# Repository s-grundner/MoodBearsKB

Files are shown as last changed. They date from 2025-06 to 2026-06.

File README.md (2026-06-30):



# Custom Keyboard

Personalized Totem Keyboard: PCB and Case Completely reworked.

Inspirations:

- [TOTEM Keyboard](https://github.com/GEIGEIGEIST/TOTEM)

## Revision 1

Revision 1 is focused on using parts i have at home. This impedes the case design a little bit though, as the THT diodes intersect with the Original switch plate

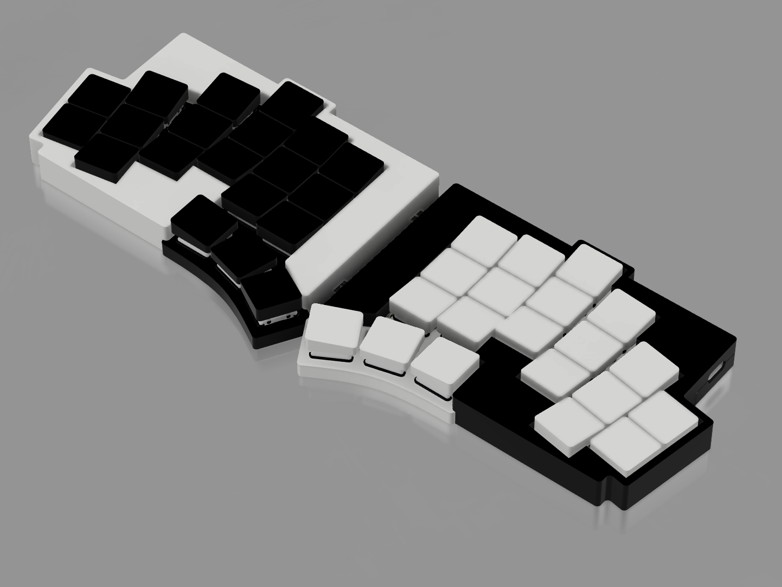
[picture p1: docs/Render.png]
KB
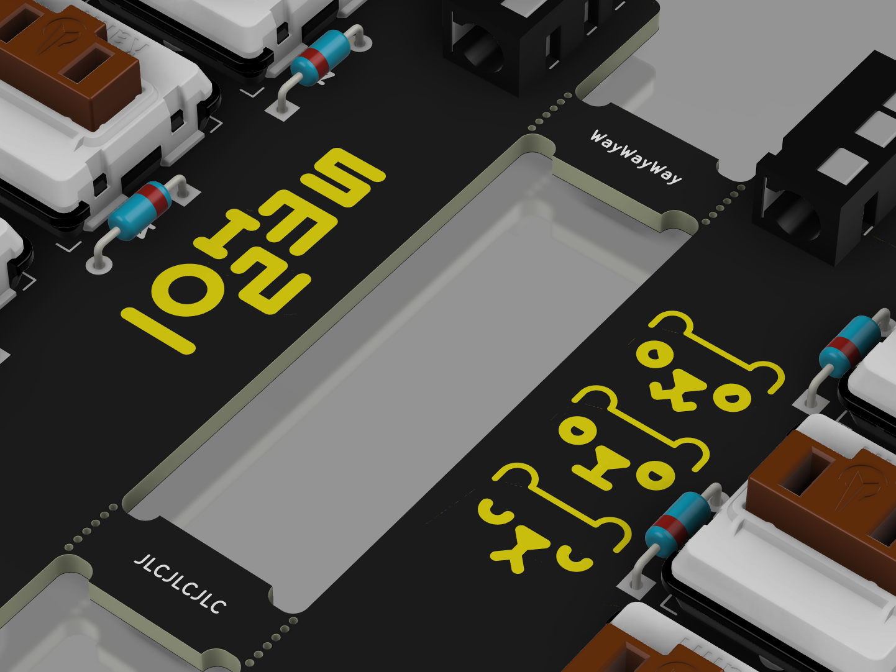
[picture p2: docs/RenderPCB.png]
PCB
|  |  |
| :---: | :---: |
| Keyboard Preview | PCB |

```text
// Template 
//             ┏━━━━━━━━━━━┳━━━━━━━━━━━┳━━━━━━━━━━━┳━━━━━━━━━━━┳━━━━━━━━━━━┓   ┏━━━━━━━━━━━┳━━━━━━━━━━━┳━━━━━━━━━━━┳━━━━━━━━━━━┳━━━━━━━━━━━┓
//             ┃           ┃           ┃           ┃           ┃           ┃   ┃           ┃           ┃           ┃           ┃           ┃
// ┏━━━━━━━━━━━╋━━━━━━━━━━━╋━━━━━━━━━━━╋━━━━━━━━━━━╋━━━━━━━━━━━╋━━━━━━━━━━━┫   ┣━━━━━━━━━━━╋━━━━━━━━━━━╋━━━━━━━━━━━╋━━━━━━━━━━━╋━━━━━━━━━━━╋━━━━━━━━━━━┓
// ┃    ESC    ┃           ┃    ALT    ┃   CTRL    ┃   SHIFT   ┃           ┃   ┃           ┃   SHIFT   ┃   CTRL    ┃    ALT    ┃           ┃   BSPC    ┃
// ┣━━━━━━━━━━━╋━━━━━━━━━━━╋━━━━━━━━━━━╋━━━━━━━━━━━╋━━━━━━━━━━━╋━━━━━━━━━━━┫   ┣━━━━━━━━━━━╋━━━━━━━━━━━╋━━━━━━━━━━━╋━━━━━━━━━━━╋━━━━━━━━━━━╋━━━━━━━━━━━┫
// ┃    TAB    ┃           ┃           ┃           ┃           ┃           ┃   ┃           ┃           ┃           ┃           ┃           ┃   ENTER   ┃
// ┗━━━━━━━━━━━┻━━━━━━━━━━━┻━━━━━━━━━━━╋━━━━━━━━━━━╋━━━━━━━━━━━╋━━━━━━━━━━━┫   ┣━━━━━━━━━━━╋━━━━━━━━━━━╋━━━━━━━━━━━╋━━━━━━━━━━━┻━━━━━━━━━━━┻━━━━━━━━━━━┛
//                                     ┃   SUPER   ┃    SYM    ┃    SPC    ┃   ┃    SPC    ┃    NUM    ┃    DEL    ┃
//                                     ┗━━━━━━━━━━━┻━━━━━━━━━━━┻━━━━━━━━━━━┛   ┗━━━━━━━━━━━┻━━━━━━━━━━━┻━━━━━━━━━━━┛
```

## Firmware Update

1. Flash settings_reset to dongle, left, and right.
2. Reboot/power-cycle all three devices.
3. Flash normal firmware to dongle first.
4. Reboot dongle.
5. Flash normal firmware to left and right.
6. Reboot each half again.
7. Wait for the halves to pair to the dongle.

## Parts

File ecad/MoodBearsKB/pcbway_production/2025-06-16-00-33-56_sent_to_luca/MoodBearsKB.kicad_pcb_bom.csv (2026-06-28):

Designator | Quantity | Value | Footprint | Package | MPN | DNP | Mount_Type
BAT+1, BAT+2 | 2 | + | BatteryPad |  |  |  | tht
BATGND1, BATGND2 | 2 | - | BatteryPad |  |  |  | tht
DL1, DL10, DL11, DL12, DL13, DL14, DL15, DL16, DL17, DL18, DL19, DL2, DL20, DL3, DL4, DL5, DL6, DL7, DL8, DL9, DR1, DR10, DR11, DR12, DR13, DR14, DR15, DR16, DR17, DR18, DR19, DR2, DR20, DR3, DR4, DR5, DR6, DR7, DR8, DR9 | 40 | D_Small | Diode_SOD27 |  |  |  | tht
J1, J2 | 2 | MJ-4PP-9 | MJ-4PP-9_1side |  |  |  | tht
PSW1, PSW2 | 2 | SW_SPDT | MSK12C02 |  |  |  | smt
RSW1, RSW2 | 2 | SW_Push | SKHLLCA010 |  |  |  | tht
SWL1, SWL10, SWL11, SWL12, SWL13, SWL14, SWL15, SWL16, SWL17, SWL18, SWL19, SWL2, SWL20, SWL3, SWL4, SWL5, SWL6, SWL7, SWL8, SWL9, SWR1, SWR10, SWR11, SWR12, SWR13, SWR14, SWR15, SWR16, SWR17, SWR18, SWR19, SWR2, SWR20, SWR3, SWR4, SWR5, SWR6, SWR7, SWR8, SWR9 | 40 | SW_Push_45deg | Kailh_socket_PG1350_optional |  |  |  | tht
U1, U2 | 2 | xiao-ble | xiao-ble-smd-cutout |  |  |  | tht

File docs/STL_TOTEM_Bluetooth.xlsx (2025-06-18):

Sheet: Notizblatt
Stückliste Notizblatt
Lfd. Nr. | Stück- zahl | Ein- heit | Benennung | Referenzkennzeichen | Lieferant | Bestellnummer | MCd | Preis/EH | VE | Bemerkung
1 | 40 | STK | Choc V1 Switches | SWL1-20, SWR1-20 | keeb.supply |  |  | 0.950 | 10 | Ambients Silent Linear Twilight (https://keeb.supply/products/twilight-low-profile-switches?variant=98b7ff54-19e0-47d5-9570-212822195d1c)
2 | 40 | STK | Kailh-Choc 1350 Hot Swap Sockets | SWL1-20, SWR1-20 | keeb.supply |  |  | 0.220 | 10 | Choc Kailh hotswap sockets (https://keeb.supply/products/kailh-hotswap-sockets?variant=2ac70e4a-befb-43b0-9321-8c5636b8d5d3)
3 | 40 | STK | 1N4148 | DL1-20, DR1-20 | s-grundner (https://github.com/s-grundner) | 1N 4148 |  | 0.000 | 1 | THT version
4 | 2 | STK | Reset Button | RSW1,2 | keeb.supply | SKHLLCA010 |  | 0.6 | 1 | Alps
5 | 1 | STK | PCB |  | l-langegger |  |  | 0 | 5 | PCB-Way via Sammelbestellung
6 | 2 | STK | LiPo Akku 3.7V |  | reichelt.de | AKKU 30851 |  | 5.300 | 1 | 140mAh, L=24.4mm, B=13.1mm, H=6.1mm
7 | 3 | STK | Seeed Studio XIAO nRF52840 | U1,2 | reichelt.de | XIAO NRF52840 |  | 12.800 | 1
8 | 2 | STK | SPST Power Switch | PSW1,2 | keeb.supply (https://keebd.com/en-de) | MSK-12C02 |  | 0.800 | 1 | Switch Mini 7 Pin 2 Slide Positions (https://keeb.supply/products/smd-slide-switch?variant=c8e601de-b898-4b81-b8a4-a918e330e673)
9 | 4 | STK | Gummi Füße |  | amazon.de |  |  | 0.040 | 100 | Round Silicone Rubber Feet (https://www.amazon.de/dp/B076ND94QV?psc=1&ref_=cm_sw_r_cp_ud_ct_W7SYHVF00B5TN0Z39RR0)
10 | 4 | STK | Brass Standoffs
11 | 1 | STK | Shipping Reichelt |  |  |  |  | 5.95 | 1
12 | 1 | STK | Shipping JLC |  |  |  |  |  | 1
Nach dieser Linie dürfen keine Daten mehr eingegeben werden

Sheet: Eingabe
Jahrgang: |  |  |  |  |  | Toleranz: |  |  |  | Dokumentart: | Stückliste | Sachnummer, Dateiname:
Katalognummer: |  |  |  |  |  | Werkstoff: |  | FR4 |  | Datum: | 2025-06-16 | Stückliste:
Vorname Nachname: |  |  |  | Simon Grundner |  | Geprüft : |  |  |  | Version: | 1.0 | Materialkalkulation:
Kurzzeichen: |  |  |  | GruS |  | Betreuer: |  |  |  | Revision: | 1 | Einheiten zur Bestellung: |  | 1
Benennung (Projekt) / Version: |  |  |  | TOTEM - Bluetooth |  | Freigabe. |  |  |  | Dokumentenstatus: | Fertigung | Ausbildungsrichtung:
Benennung (Projekt) Zeile 2: |  |  |  | 40 Key Split Ergomech KB |  | Sprache: |  | DE |  | Maßstab: | ohne | Technische Informatik
Lfd. Nr. | Stück- zahl | Ein- heit | Benennung | Referenzkennzeichen | Lieferant | Bestellnummer | MCd | Preis/EH | VE | Bemerkung | Preisvorschau 135.42 €/STK | 1 EH inkl. 10% GK = 112.85 € zuzgl. 20% MwSt. = 135.42 € Bestellnummer Bestellmenge Bestelltextkontrolle - Ben. Ref.KZ - keine Feldlängenkontrolle
1 | 40 | STK | Choc V1 Switches | SWL1-20, SWR1-20 | keeb.supply |  |  | 0.95 | 10 | Ambients Silent Linear Twilight (https://keeb.supply/products/twilight-low-profile-switches?variant=98b7ff54-19e0-47d5-9570-212822195d1c) | 38.0000 | 0 | 40 STK | Choc V1 Switches SWL1-20, SWR1-20
2 | 40 | STK | Kailh-Choc 1350 Hot Swap Sockets | SWL1-20, SWR1-20 | keeb.supply |  |  | 0.22 | 10 | Choc Kailh hotswap sockets (https://keeb.supply/products/kailh-hotswap-sockets?variant=2ac70e4a-befb-43b0-9321-8c5636b8d5d3) | 8.8000 | 0 | 40 STK | Kailh-Choc 1350 Hot Swap Sockets SWL1-20, SWR1-20
3 | 40 | STK | 1N4148 | DL1-20, DR1-20 | s-grundner (https://github.com/s-grundner) | 1N 4148 |  | 0 | 1 | THT version
4 | 2 | STK | Reset Button | RSW1,2 | keeb.supply | SKHLLCA010 |  | 0.6 | 1 | Alps | 1.2000 | SKHLLCA010 | 2 STK | Reset Button RSW1,2
5 | 1 | STK | PCB |  | l-langegger |  |  | 0 | 5 | PCB-Way via Sammelbestellung
6 | 2 | STK | LiPo Akku 3.7V |  | reichelt.de | AKKU 30851 |  | 5.3 | 1 | 140mAh, L=24.4mm, B=13.1mm, H=6.1mm | 10.6000 | AKKU 30851 | 2 STK | LiPo Akku 3.7V
7 | 3 | STK | Seeed Studio XIAO nRF52840 | U1,2 | reichelt.de | XIAO NRF52840 |  | 12.8 | 1 |  | 38.4000 | XIAO NRF52840 | 3 STK | Seeed Studio XIAO nRF52840 U1,2
8 | 2 | STK | SPST Power Switch | PSW1,2 | keeb.supply (https://keebd.com/en-de) | MSK-12C02 |  | 0.8 | 1 | Switch Mini 7 Pin 2 Slide Positions (https://keeb.supply/products/smd-slide-switch?variant=c8e601de-b898-4b81-b8a4-a918e330e673) | 1.6000 | MSK-12C02 | 2 STK | SPST Power Switch PSW1,2
9 | 4 | STK | Gummi Füße |  | amazon.de |  |  | 0.0399 | 100 | Round Silicone Rubber Feet (https://www.amazon.de/dp/B076ND94QV?psc=1&ref_=cm_sw_r_cp_ud_ct_W7SYHVF00B5TN0Z39RR0) | 3.9900 | 0 | 100 STK | Gummi Füße
1
11
12
13
14
15
16
17
18
19
20
21
22
23
24
25
26
27
28
29
30
31

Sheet: Stückliste (1)
1 | 2 | 3 | 4 |  | 5 |  |  |  |  | 6 |  | 7
Lfd. Nr. | Stück- zahl | Ein- heit | Benennung |  | Lieferant / Bestellnummer |  |  |  |  | MCd |  | Bemerkung
1 | 40 | STK | Choc V1 Switches SWL1-20, SWR1-20 |  | keeb.supply |  |  |  |  |  |  | Ambients Silent Linear Twilight
2 | 40 | STK | Kailh-Choc 1350 Hot Swap Sockets SWL1-20, SWR1-20 |  | keeb.supply |  |  |  |  |  |  | Choc Kailh hotswap sockets
3 | 40 | STK | 1N4148 DL1-20, DR1-20 |  | s-grundner 1N 4148 |  |  |  |  |  |  | THT version
4 | 2 | STK | Reset Button RSW1,2 |  | keeb.supply SKHLLCA010 |  |  |  |  |  |  | Alps
5 | 1 | STK | PCB |  | l-langegger |  |  |  |  |  |  | PCB-Way via Sammelbestellung
6 | 2 | STK | LiPo Akku 3.7V |  | reichelt.de AKKU 30851 |  |  |  |  |  |  | 140mAh, L=24.4mm, B=13.1mm, H=6.1mm
7 | 3 | STK | Seeed Studio XIAO nRF52840 U1,2 |  | reichelt.de XIAO NRF52840
8 | 2 | STK | SPST Power Switch PSW1,2 |  | keeb.supply MSK-12C02 |  |  |  |  |  |  | Switch Mini 7 Pin 2 Slide Positions
9 | 4 | STK | Gummi Füße |  | amazon.de |  |  |  |  |  |  | Round Silicone Rubber Feet
1
11
12
13
14
15
16
17
18
19
20
21
22
23
24
25
Sachnummer, Dateiname: |  |  |  | Name: |  |  |  | Toleranz: |  |  |  | Werkstoff:
 |  |  |  | Simon Grundner |  |  |  |  |  |  |  | FR4
 |  |  |  | ID-Nr.: | Gez.: | Geprüft: | Betreuer: | Dokumentart:
 |  |  |  |  | GruS |  |  | Stückliste
 |  |  |  | Benennung: |  |  |  | Version: |  |  | Revision: |  | Dokumentenstatus:
 |  |  |  | TOTEM - Bluetooth |  |  |  | 1.0 |  |  | 1 |  | Fertigung
HTBLuVA Salzburg
 |  |  |  |  |  |  |  | Maßstab: | Spr.: |  | Datum:
Technische Informatik |  |  |  | 40 Key Split Ergomech KB |  |  |  | ohne | DE |  | 2025-06-16

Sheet: Stückliste (2)
1 | 2 | 3 | 4 |  | 5 |  |  |  |  | 6 |  | 7
Lfd. Nr. | Stück- zahl | Ein- heit | Benennung |  | Lieferant / Bestellnummer |  |  |  |  | MCd |  | Bemerkung
26
27
28
29
30
31
Sachnummer, Dateiname: |  |  |  | Name: |  |  |  | Toleranz: |  |  |  | Werkstoff:
 |  |  |  | Simon Grundner |  |  |  |  |  |  |  | FR4
 |  |  |  | ID-Nr.: | Gez.: | Geprüft: | Betreuer: | Dokumentart:
 |  |  |  |  | GruS |  |  | Stückliste
 |  |  |  | Benennung: |  |  |  | Version: |  |  | Revision: |  | Dokumentenstatus:
 |  |  |  | TOTEM - Bluetooth |  |  |  | 1.0 |  |  | 1 |  | Fertigung
HTBLuVA Salzburg
 |  |  |  |  |  |  |  | Maßstab: | Spr.: |  | Datum:
Technische Informatik |  |  |  | 40 Key Split Ergomech KB |  |  |  | ohne | DE |  | 2025-06-16

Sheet: Stückliste (3)
1 | 2 | 3 | 4 |  | 5 |  |  |  |  | 6 |  | 7
Lfd. Nr. | Stück- zahl | Ein- heit | Benennung |  | Lieferant / Bestellnummer |  |  |  |  | MCd |  | Bemerkung
Sachnummer, Dateiname: |  |  |  | Name: |  |  |  | Toleranz: |  |  |  | Werkstoff:
 |  |  |  | Simon Grundner |  |  |  |  |  |  |  | FR4
 |  |  |  | ID-Nr.: | Gez.: | Geprüft: | Betreuer: | Dokumentart:
 |  |  |  |  | GruS |  |  | Stückliste
 |  |  |  | Benennung: |  |  |  | Version: |  |  | Revision: |  | Dokumentenstatus:
 |  |  |  | TOTEM - Bluetooth |  |  |  | 1.0 |  |  | 1 |  | Fertigung
HTBLuVA Salzburg
 |  |  |  |  |  |  |  | Maßstab: | Spr.: |  | Datum:
Technische Informatik |  |  |  | 40 Key Split Ergomech KB |  |  |  | ohne | DE |  | 2025-06-16

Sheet: Stückliste (4)
1 | 2 | 3 | 4 |  | 5 |  |  |  |  | 6 |  | 7
Lfd. Nr. | Stück- zahl | Ein- heit | Benennung |  | Lieferant / Bestellnummer |  |  |  |  | MCd |  | Bemerkung
Sachnummer, Dateiname: |  |  |  | Name: |  |  |  | Toleranz: |  |  |  | Werkstoff:
 |  |  |  | Simon Grundner |  |  |  |  |  |  |  | FR4
 |  |  |  | ID-Nr.: | Gez.: | Geprüft: | Betreuer: | Dokumentart:
 |  |  |  |  | GruS |  |  | Stückliste
 |  |  |  | Benennung: |  |  |  | Version: |  |  | Revision: |  | Dokumentenstatus:
 |  |  |  | TOTEM - Bluetooth |  |  |  | 1.0 |  |  | 1 |  | Fertigung
HTBLuVA Salzburg
 |  |  |  |  |  |  |  | Maßstab: | Spr.: |  | Datum:
Technische Informatik |  |  |  | 40 Key Split Ergomech KB |  |  |  | ohne | DE |  | 2025-06-16

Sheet: Stückliste (5)
1 | 2 | 3 | 4 |  | 5 |  |  |  |  | 6 |  | 7
Lfd. Nr. | Stück- zahl | Ein- heit | Benennung |  | Lieferant / Bestellnummer |  |  |  |  | MCd |  | Bemerkung
Sachnummer, Dateiname: |  |  |  | Name: |  |  |  | Toleranz: |  |  |  | Werkstoff:
 |  |  |  | Simon Grundner |  |  |  |  |  |  |  | FR4
 |  |  |  | ID-Nr.: | Gez.: | Geprüft: | Betreuer: | Dokumentart:
 |  |  |  |  | GruS |  |  | Stückliste
 |  |  |  | Benennung: |  |  |  | Version: |  |  | Revision: |  | Dokumentenstatus:
 |  |  |  | TOTEM - Bluetooth |  |  |  | 1.0 |  |  | 1 |  | Fertigung
HTBLuVA Salzburg
 |  |  |  |  |  |  |  | Maßstab: | Spr.: |  | Datum:
Technische Informatik |  |  |  | 40 Key Split Ergomech KB |  |  |  | ohne | DE |  | 2025-06-16

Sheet: Materialkalkulation (1)
1 | 2 | 3 | 4 |  |  | 5 |  |  |  |  |  |  | 6
Lfd. Nr. | Stück- zahl | Ein- heit | Benennung |  |  | Lieferant / Bestellnummer |  |  |  |  |  |  | Preis
 |  |  |  |  |  |  |  |  |  |  |  |  | Einzel
1 | 40 | STK | Choc V1 Switches |  |  | keeb.supply / |  |  |  |  |  |  | 0.950
2 | 40 | STK | Kailh-Choc 1350 Hot Swap Sockets |  |  | keeb.supply / |  |  |  |  |  |  | 0.220
3 | 40 | STK | 1N4148 |  |  | s-grundner / 1N 4148 |  |  |  |  |  |  | 0.000
4 | 2 | STK | Reset Button |  |  | keeb.supply / SKHLLCA010 |  |  |  |  |  |  | 0.600
5 | 1 | STK | PCB |  |  | l-langegger / |  |  |  |  |  |  | 0.000
6 | 2 | STK | LiPo Akku 3.7V |  |  | reichelt.de / AKKU 30851 |  |  |  |  |  |  | 5.300
7 | 3 | STK | Seeed Studio XIAO nRF52840 |  |  | reichelt.de / XIAO NRF52840 |  |  |  |  |  |  | 12.800
8 | 2 | STK | SPST Power Switch |  |  | keeb.supply / MSK-12C02 |  |  |  |  |  |  | 0.800
9 | 4 | STK | Gummi Füße |  |  | amazon.de / |  |  |  |  |  |  | 0.040
1
11
12
13
14
15
16
17
18
19
20
21
22
23
24
25
26
27
28
29
30
31
 |  |  |  |  |  | Übertrag:
 |  |  |  |  |  | Materialpreis |  |  |  |  |  |  | €98.760
 |  |  |  |  |  | Materialgemeinkosten (10%) |  |  |  |  |  |  | €9.876
 |  |  |  |  |  | Materialverkaufspreis |  |  |  |  |  |  | €108.636
Sachnummer, Dateiname: |  |  |  | Name: |  |  |  |  | Toleranz: |  |  | Werkstoff:
 |  |  |  | Simon Grundner |  |  |  |  |  |  |  | FR4
 |  |  |  | ID-Nr.: | Gez.: |  | Geprüft: | Betreuer: | Dokumentart:
 |  |  |  |  | GruS |  |  |  | Materialkalkulation
 |  |  |  | Benennung: |  |  |  |  | Version: |  | Revision: |  | Dokumentenstatus:
 |  |  |  | TOTEM - Bluetooth |  |  |  |  | 1.0 |  | 1 |  | Fertigung
HTBLuVA Salzburg
 |  |  |  |  |  |  |  |  | Maßstab: | Spr.: | Datum:
Technische Informatik |  |  |  | 40 Key Split Ergomech KB |  |  |  |  | ohne | DE | 2025-06-16

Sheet: Materialkalkulation (2)
1 | 2 | 3 | 4 |  |  | 5 |  |  |  |  |  |  | 6
Lfd. Nr. | Stück- zahl | Ein- heit | Benennung |  |  | Lieferant / Bestellnummer |  |  |  |  |  |  | Preis
 |  |  |  |  |  |  |  |  |  |  |  |  | Einzel
 |  |  |  |  |  | Übertrag: |  |  |  |  |  |  | €108.636
 |  |  |  |  |  | Materialpreis |  |  |  |  |  |  | €0.000
 |  |  |  |  |  | Materialgemeinkosten (10%) |  |  |  |  |  |  | €0.000
 |  |  |  |  |  | Materialverkaufspreis |  |  |  |  |  |  | €108.636
Sachnummer, Dateiname: |  |  |  | Name: |  |  |  |  | Toleranz: |  |  | Werkstoff:
 |  |  |  | Simon Grundner |  |  |  |  |  |  |  | FR4
 |  |  |  | ID-Nr.: | Gez.: |  | Geprüft: | Betreuer: | Dokumentart:
 |  |  |  |  | GruS |  |  |  | Materialkalkulation
 |  |  |  | Benennung: |  |  |  |  | Version: |  | Revision: |  | Dokumentenstatus:
 |  |  |  | TOTEM - Bluetooth |  |  |  |  | 1.0 |  | 1 |  | Fertigung
HTBLuVA Salzburg
 |  |  |  |  |  |  |  |  | Maßstab: | Spr.: | Datum:
Technische Informatik |  |  |  | 40 Key Split Ergomech KB |  |  |  |  | ohne | DE | 2025-06-16

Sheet: Materialkalkulation (3)
1 | 2 | 3 | 4 |  |  | 5 |  |  |  |  |  |  | 6
Lfd. Nr. | Stück- zahl | Ein- heit | Benennung |  |  | Lieferant / Bestellnummer |  |  |  |  |  |  | Preis
 |  |  |  |  |  |  |  |  |  |  |  |  | Einzel
 |  |  |  |  |  | Übertrag: |  |  |  |  |  |  | €108.636
 |  |  |  |  |  | Materialpreis |  |  |  |  |  |  | €0.000
 |  |  |  |  |  | Materialgemeinkosten (10%) |  |  |  |  |  |  | €0.000
 |  |  |  |  |  | Materialverkaufspreis |  |  |  |  |  |  | €108.636
Sachnummer, Dateiname: |  |  |  | Name: |  |  |  |  | Toleranz: |  |  | Werkstoff:
 |  |  |  | Simon Grundner |  |  |  |  |  |  |  | FR4
 |  |  |  | ID-Nr.: | Gez.: |  | Geprüft: | Betreuer: | Dokumentart:
 |  |  |  |  | GruS |  |  |  | Materialkalkulation
 |  |  |  | Benennung: |  |  |  |  | Version: |  | Revision: |  | Dokumentenstatus:
 |  |  |  | TOTEM - Bluetooth |  |  |  |  | 1.0 |  | 1 |  | Fertigung
HTBLuVA Salzburg
 |  |  |  |  |  |  |  |  | Maßstab: | Spr.: | Datum:
Technische Informatik |  |  |  | 40 Key Split Ergomech KB |  |  |  |  | ohne | DE | 2025-06-16
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

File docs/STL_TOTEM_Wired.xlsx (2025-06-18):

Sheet: Notizblatt
Stückliste Notizblatt
Lfd. Nr. | Stück- zahl | Ein- heit | Benennung | Referenzkennzeichen | Lieferant | Bestellnummer | MCd | Preis/EH | VE | Bemerkung
1 | 40 | STK | Choc V1 Switches | SWL1-20, SWR1-20 | keeb.supply | Twilight-10 |  | 0.950 | 10 | Ambients Silent Linear Twilight (https://keeb.supply/products/twilight-low-profile-switches?variant=98b7ff54-19e0-47d5-9570-212822195d1c)
2 | 40 | STK | Kailh-Choc 1350 Hot Swap Sockets | SWL1-20, SWR1-20 | keeb.supply | Kailh-hs-choc |  | 0.220 | 10 | Choc Kailh hotswap sockets (https://keeb.supply/products/kailh-hotswap-sockets?variant=2ac70e4a-befb-43b0-9321-8c5636b8d5d3)
3 | 40 | STK | 1N4148 | DL1-20, DR1-20 | s-grundner (https://github.com/s-grundner) | 1N 4148 |  | 0.000 | 1 | THT version
4 | 2 | STK | Reset Button | RSW1,2 | keeb.supply | SKHLLCA010 |  | 0.600 | 1 | Alps
5 | 1 | STK | PCB |  | l-langegger |  |  | 0 | 5 | PCB-Way via Sammelbestellung
6 | 2 | STK | Seeed Studio XIAO RP2040 | U1,2 | reichelt.de | XIAO RP2040 |  | 5.540 | 1
7 | 2 | STK | TRRS Connector | J1,2 | keeb.supply | PJ320A |  | 0.750 | 2 | 2x TRRS jacks PJ320A (https://keeb.supply/products/trrs-jack)
8 | 1 | STK | TRRS Cable |  | keeb.supply |  |  | 6.000 | 1 | Metal TRRS Cable (https://keeb.supply/products/metal-trrs-cable)
9 | 4 | STK | Gummi Noppen |  | amazon.de |  |  | 0.040 | 100 | Round Silicone Rubber Feet (https://www.amazon.de/dp/B076ND94QV?psc=1&ref_=cm_sw_r_cp_ud_ct_W7SYHVF00B5TN0Z39RR0)
10 | 4 | STK | Tenting Feet |  | keebd.com (https://keebd.com/en-de) |  |  | 3.487 | 4 | Tenting Feet (https://keebd.com/en-de/products/tenting-feet)
11 | 4 | STK | Brass Standoffs
12 | 1 | STK | Shipping Reichelt |  |  |  |  | 5.95 | 1
13 | 1 | STK | Shipping Keebd |  |  |  |  | 11.95 | 1
14 | 1 | STK | Shipping JLC |  |  |  |  | 15.65 | 1
Nach dieser Linie dürfen keine Daten mehr eingegeben werden

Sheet: Eingabe
Jahrgang: |  |  |  |  |  | Toleranz: |  |  |  | Dokumentart: | Stückliste | Sachnummer, Dateiname:
Katalognummer: |  |  |  |  |  | Werkstoff: |  | FR4 |  | Datum: | 2025-06-16 | Stückliste:
Vorname Nachname: |  |  |  | Simon Grundner |  | Geprüft : |  |  |  | Version: | 1.0 | Materialkalkulation:
Kurzzeichen: |  |  |  | GruS |  | Betreuer: |  |  |  | Revision: | 1 | Einheiten zur Bestellung: |  | 1
Benennung (Projekt) / Version: |  |  |  | TOTEM - Wired |  | Freigabe. |  |  |  | Dokumentenstatus: | Fertigung | Ausbildungsrichtung:
Benennung (Projekt) Zeile 2: |  |  |  | 40 Key Split Ergomech KB |  | Sprache: |  | DE |  | Maßstab: | ohne | Technische Informatik
Lfd. Nr. | Stück- zahl | Ein- heit | Benennung | Referenzkennzeichen | Lieferant | Bestellnummer | MCd | Preis/EH | VE | Bemerkung | Preisvorschau 93.16 €/STK | 1 EH inkl. 10% GK = 77.63 € zuzgl. 20% MwSt. = 93.16 € Bestellnummer Bestellmenge Bestelltextkontrolle - Ben. Ref.KZ - keine Feldlängenkontrolle
1 | 40 | STK | Choc V1 Switches | SWL1-20, SWR1-20 | keeb.supply | Twilight-10 |  | 0.95 | 10 | Ambients Silent Linear Twilight (https://keeb.supply/products/twilight-low-profile-switches?variant=98b7ff54-19e0-47d5-9570-212822195d1c) | 38.0000 | Twilight-10 | 40 STK | Choc V1 Switches SWL1-20, SWR1-20
2 | 40 | STK | Kailh-Choc 1350 Hot Swap Sockets | SWL1-20, SWR1-20 | keeb.supply | Kailh-hs-choc |  | 0.22 | 10 | Choc Kailh hotswap sockets (https://keeb.supply/products/kailh-hotswap-sockets?variant=2ac70e4a-befb-43b0-9321-8c5636b8d5d3) | 8.8000 | Kailh-hs-choc | 40 STK | Kailh-Choc 1350 Hot Swap Sockets SWL1-20, SWR1-20
3 | 40 | STK | 1N4148 | DL1-20, DR1-20 | s-grundner (https://github.com/s-grundner) | 1N 4148 |  | 0 | 1 | THT version
4 | 2 | STK | Reset Button | RSW1,2 | keeb.supply | SKHLLCA010 |  | 0.6 | 1 | Alps | 1.2000 | SKHLLCA010 | 2 STK | Reset Button RSW1,2
 | 1 | STK | PCB |  | l-langegger |  |  | 0 | 5 | PCB-Way via Sammelbestellung
 | 2 | STK | Seeed Studio XIAO RP2040 | U1,2 | reichelt.de | XIAO RP2040 |  | 5.54 | 1 |  | 11.0800 | XIAO RP2040 | 2 STK | Seeed Studio XIAO RP2040 U1,2
 | 2 | STK | TRRS Connector | J1,2 | keeb.supply | PJ320A |  | 0.75 | 2 | 2x TRRS jacks PJ320A (https://keeb.supply/products/trrs-jack) | 1.5000 | PJ320A | 2 STK | TRRS Connector J1,2
 | 1 | STK | TRRS Cable |  | keeb.supply |  |  | 6 | 1 | Metal TRRS Cable (https://keeb.supply/products/metal-trrs-cable) | 6.0000 | 0 | 1 STK | TRRS Cable
 | 4 | STK | Gummi Noppen |  | amazon.de |  |  | 0.0399 | 100 | Round Silicone Rubber Feet (https://www.amazon.de/dp/B076ND94QV?psc=1&ref_=cm_sw_r_cp_ud_ct_W7SYHVF00B5TN0Z39RR0) | 3.9900 | 0 | 100 STK | Gummi Noppen

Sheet: Stückliste (1)
1 | 2 | 3 | 4 |  | 5 |  |  |  |  | 6 |  | 7
Lfd. Nr. | Stück- zahl | Ein- heit | Benennung |  | Lieferant / Bestellnummer |  |  |  |  | MCd |  | Bemerkung
1 | 40 | STK | Choc V1 Switches SWL1-20, SWR1-20 |  | keeb.supply Twilight-10 |  |  |  |  |  |  | Ambients Silent Linear Twilight
2 | 40 | STK | Kailh-Choc 1350 Hot Swap Sockets SWL1-20, SWR1-20 |  | keeb.supply Kailh-hs-choc |  |  |  |  |  |  | Choc Kailh hotswap sockets
3 | 40 | STK | 1N4148 DL1-20, DR1-20 |  | s-grundner 1N 4148 |  |  |  |  |  |  | THT version
4 | 2 | STK | Reset Button RSW1,2 |  | keeb.supply SKHLLCA010 |  |  |  |  |  |  | Alps
 | 1 | STK | PCB |  | l-langegger |  |  |  |  |  |  | PCB-Way via Sammelbestellung
 | 2 | STK | Seeed Studio XIAO RP2040 U1,2 |  | reichelt.de XIAO RP2040
 | 2 | STK | TRRS Connector J1,2 |  | keeb.supply PJ320A |  |  |  |  |  |  | 2x TRRS jacks PJ320A
 | 1 | STK | TRRS Cable |  | keeb.supply |  |  |  |  |  |  | Metal TRRS Cable
 | 4 | STK | Gummi Noppen |  | amazon.de |  |  |  |  |  |  | Round Silicone Rubber Feet
Sachnummer, Dateiname: |  |  |  | Name: |  |  |  | Toleranz: |  |  |  | Werkstoff:
 |  |  |  | Simon Grundner |  |  |  |  |  |  |  | FR4
 |  |  |  | ID-Nr.: | Gez.: | Geprüft: | Betreuer: | Dokumentart:
 |  |  |  |  | GruS |  |  | Stückliste
 |  |  |  | Benennung: |  |  |  | Version: |  |  | Revision: |  | Dokumentenstatus:
 |  |  |  | TOTEM - Wired |  |  |  | 1.0 |  |  | 1 |  | Fertigung
HTBLuVA Salzburg
 |  |  |  |  |  |  |  | Maßstab: | Spr.: |  | Datum:
Technische Informatik |  |  |  | 40 Key Split Ergomech KB |  |  |  | ohne | DE |  | 2025-06-16

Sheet: Stückliste (2)
1 | 2 | 3 | 4 |  | 5 |  |  |  |  | 6 |  | 7
Lfd. Nr. | Stück- zahl | Ein- heit | Benennung |  | Lieferant / Bestellnummer |  |  |  |  | MCd |  | Bemerkung
Sachnummer, Dateiname: |  |  |  | Name: |  |  |  | Toleranz: |  |  |  | Werkstoff:
 |  |  |  | Simon Grundner |  |  |  |  |  |  |  | FR4
 |  |  |  | ID-Nr.: | Gez.: | Geprüft: | Betreuer: | Dokumentart:
 |  |  |  |  | GruS |  |  | Stückliste
 |  |  |  | Benennung: |  |  |  | Version: |  |  | Revision: |  | Dokumentenstatus:
 |  |  |  | TOTEM - Wired |  |  |  | 1.0 |  |  | 1 |  | Fertigung
HTBLuVA Salzburg
 |  |  |  |  |  |  |  | Maßstab: | Spr.: |  | Datum:
Technische Informatik |  |  |  | 40 Key Split Ergomech KB |  |  |  | ohne | DE |  | 2025-06-16

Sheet: Stückliste (3)
1 | 2 | 3 | 4 |  | 5 |  |  |  |  | 6 |  | 7
Lfd. Nr. | Stück- zahl | Ein- heit | Benennung |  | Lieferant / Bestellnummer |  |  |  |  | MCd |  | Bemerkung
Sachnummer, Dateiname: |  |  |  | Name: |  |  |  | Toleranz: |  |  |  | Werkstoff:
 |  |  |  | Simon Grundner |  |  |  |  |  |  |  | FR4
 |  |  |  | ID-Nr.: | Gez.: | Geprüft: | Betreuer: | Dokumentart:
 |  |  |  |  | GruS |  |  | Stückliste
 |  |  |  | Benennung: |  |  |  | Version: |  |  | Revision: |  | Dokumentenstatus:
 |  |  |  | TOTEM - Wired |  |  |  | 1.0 |  |  | 1 |  | Fertigung
HTBLuVA Salzburg
 |  |  |  |  |  |  |  | Maßstab: | Spr.: |  | Datum:
Technische Informatik |  |  |  | 40 Key Split Ergomech KB |  |  |  | ohne | DE |  | 2025-06-16

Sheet: Stückliste (4)
1 | 2 | 3 | 4 |  | 5 |  |  |  |  | 6 |  | 7
Lfd. Nr. | Stück- zahl | Ein- heit | Benennung |  | Lieferant / Bestellnummer |  |  |  |  | MCd |  | Bemerkung
Sachnummer, Dateiname: |  |  |  | Name: |  |  |  | Toleranz: |  |  |  | Werkstoff:
 |  |  |  | Simon Grundner |  |  |  |  |  |  |  | FR4
 |  |  |  | ID-Nr.: | Gez.: | Geprüft: | Betreuer: | Dokumentart:
 |  |  |  |  | GruS |  |  | Stückliste
 |  |  |  | Benennung: |  |  |  | Version: |  |  | Revision: |  | Dokumentenstatus:
 |  |  |  | TOTEM - Wired |  |  |  | 1.0 |  |  | 1 |  | Fertigung
HTBLuVA Salzburg
 |  |  |  |  |  |  |  | Maßstab: | Spr.: |  | Datum:
Technische Informatik |  |  |  | 40 Key Split Ergomech KB |  |  |  | ohne | DE |  | 2025-06-16

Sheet: Stückliste (5)
1 | 2 | 3 | 4 |  | 5 |  |  |  |  | 6 |  | 7
Lfd. Nr. | Stück- zahl | Ein- heit | Benennung |  | Lieferant / Bestellnummer |  |  |  |  | MCd |  | Bemerkung
Sachnummer, Dateiname: |  |  |  | Name: |  |  |  | Toleranz: |  |  |  | Werkstoff:
 |  |  |  | Simon Grundner |  |  |  |  |  |  |  | FR4
 |  |  |  | ID-Nr.: | Gez.: | Geprüft: | Betreuer: | Dokumentart:
 |  |  |  |  | GruS |  |  | Stückliste
 |  |  |  | Benennung: |  |  |  | Version: |  |  | Revision: |  | Dokumentenstatus:
 |  |  |  | TOTEM - Wired |  |  |  | 1.0 |  |  | 1 |  | Fertigung
HTBLuVA Salzburg
 |  |  |  |  |  |  |  | Maßstab: | Spr.: |  | Datum:
Technische Informatik |  |  |  | 40 Key Split Ergomech KB |  |  |  | ohne | DE |  | 2025-06-16

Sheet: Materialkalkulation (1)
1 | 2 | 3 | 4 |  |  | 5 |  |  |  |  |  |  | 6
Lfd. Nr. | Stück- zahl | Ein- heit | Benennung |  |  | Lieferant / Bestellnummer |  |  |  |  |  |  | Preis
 |  |  |  |  |  |  |  |  |  |  |  |  | Einzel
1 | 40 | STK | Choc V1 Switches |  |  | keeb.supply / Twilight-10 |  |  |  |  |  |  | 0.950
2 | 40 | STK | Kailh-Choc 1350 Hot Swap Sockets |  |  | keeb.supply / Kailh-hs-choc |  |  |  |  |  |  | 0.220
3 | 40 | STK | 1N4148 |  |  | s-grundner / 1N 4148 |  |  |  |  |  |  | 0.000
4 | 2 | STK | Reset Button |  |  | keeb.supply / SKHLLCA010 |  |  |  |  |  |  | 0.600
 | 1 | STK | PCB |  |  | l-langegger / |  |  |  |  |  |  | 0.000
 | 2 | STK | Seeed Studio XIAO RP2040 |  |  | reichelt.de / XIAO RP2040 |  |  |  |  |  |  | 5.540
 | 2 | STK | TRRS Connector |  |  | keeb.supply / PJ320A |  |  |  |  |  |  | 0.750
 | 1 | STK | TRRS Cable |  |  | keeb.supply / |  |  |  |  |  |  | 6.000
 | 4 | STK | Gummi Noppen |  |  | amazon.de / |  |  |  |  |  |  | 0.040
 |  |  |  |  |  | Übertrag:
 |  |  |  |  |  | Materialpreis |  |  |  |  |  |  | €66.740
 |  |  |  |  |  | Materialgemeinkosten (10%) |  |  |  |  |  |  | €6.674
 |  |  |  |  |  | Materialverkaufspreis |  |  |  |  |  |  | €73.414
Sachnummer, Dateiname: |  |  |  | Name: |  |  |  |  | Toleranz: |  |  | Werkstoff:
 |  |  |  | Simon Grundner |  |  |  |  |  |  |  | FR4
 |  |  |  | ID-Nr.: | Gez.: |  | Geprüft: | Betreuer: | Dokumentart:
 |  |  |  |  | GruS |  |  |  | Materialkalkulation
 |  |  |  | Benennung: |  |  |  |  | Version: |  | Revision: |  | Dokumentenstatus:
 |  |  |  | TOTEM - Wired |  |  |  |  | 1.0 |  | 1 |  | Fertigung
HTBLuVA Salzburg
 |  |  |  |  |  |  |  |  | Maßstab: | Spr.: | Datum:
Technische Informatik |  |  |  | 40 Key Split Ergomech KB |  |  |  |  | ohne | DE | 2025-06-16

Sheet: Materialkalkulation (2)
1 | 2 | 3 | 4 |  |  | 5 |  |  |  |  |  |  | 6
Lfd. Nr. | Stück- zahl | Ein- heit | Benennung |  |  | Lieferant / Bestellnummer |  |  |  |  |  |  | Preis
 |  |  |  |  |  |  |  |  |  |  |  |  | Einzel
 |  |  |  |  |  | Übertrag: |  |  |  |  |  |  | €73.414
 |  |  |  |  |  | Materialpreis |  |  |  |  |  |  | €0.000
 |  |  |  |  |  | Materialgemeinkosten (10%) |  |  |  |  |  |  | €0.000
 |  |  |  |  |  | Materialverkaufspreis |  |  |  |  |  |  | €73.414
Sachnummer, Dateiname: |  |  |  | Name: |  |  |  |  | Toleranz: |  |  | Werkstoff:
 |  |  |  | Simon Grundner |  |  |  |  |  |  |  | FR4
 |  |  |  | ID-Nr.: | Gez.: |  | Geprüft: | Betreuer: | Dokumentart:
 |  |  |  |  | GruS |  |  |  | Materialkalkulation
 |  |  |  | Benennung: |  |  |  |  | Version: |  | Revision: |  | Dokumentenstatus:
 |  |  |  | TOTEM - Wired |  |  |  |  | 1.0 |  | 1 |  | Fertigung
HTBLuVA Salzburg
 |  |  |  |  |  |  |  |  | Maßstab: | Spr.: | Datum:
Technische Informatik |  |  |  | 40 Key Split Ergomech KB |  |  |  |  | ohne | DE | 2025-06-16

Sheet: Materialkalkulation (3)
1 | 2 | 3 | 4 |  |  | 5 |  |  |  |  |  |  | 6
Lfd. Nr. | Stück- zahl | Ein- heit | Benennung |  |  | Lieferant / Bestellnummer |  |  |  |  |  |  | Preis
 |  |  |  |  |  |  |  |  |  |  |  |  | Einzel
 |  |  |  |  |  | Übertrag: |  |  |  |  |  |  | €73.414
 |  |  |  |  |  | Materialpreis |  |  |  |  |  |  | €0.000
 |  |  |  |  |  | Materialgemeinkosten (10%) |  |  |  |  |  |  | €0.000
 |  |  |  |  |  | Materialverkaufspreis |  |  |  |  |  |  | €73.414
Sachnummer, Dateiname: |  |  |  | Name: |  |  |  |  | Toleranz: |  |  | Werkstoff:
 |  |  |  | Simon Grundner |  |  |  |  |  |  |  | FR4
 |  |  |  | ID-Nr.: | Gez.: |  | Geprüft: | Betreuer: | Dokumentart:
 |  |  |  |  | GruS |  |  |  | Materialkalkulation
 |  |  |  | Benennung: |  |  |  |  | Version: |  | Revision: |  | Dokumentenstatus:
 |  |  |  | TOTEM - Wired |  |  |  |  | 1.0 |  | 1 |  | Fertigung
HTBLuVA Salzburg
 |  |  |  |  |  |  |  |  | Maßstab: | Spr.: | Datum:
Technische Informatik |  |  |  | 40 Key Split Ergomech KB |  |  |  |  | ohne | DE | 2025-06-16
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

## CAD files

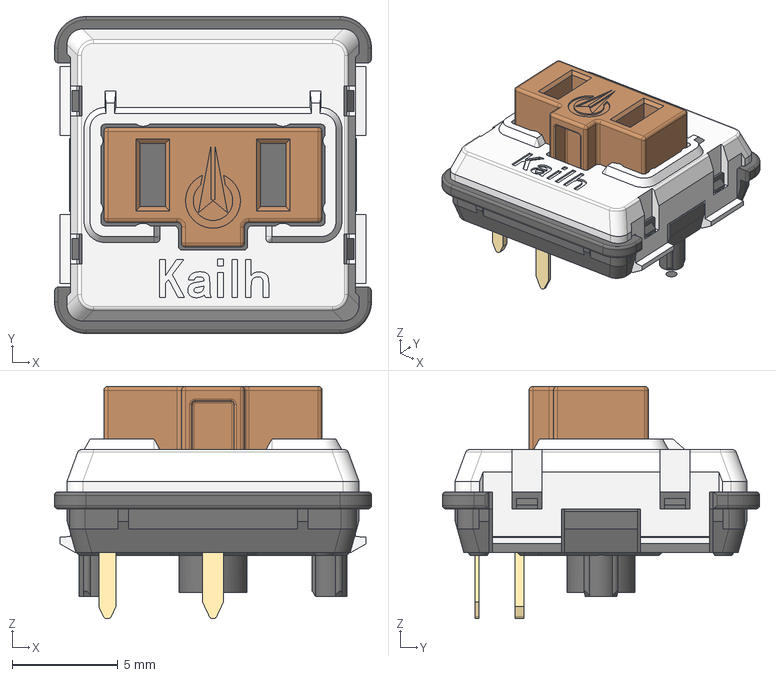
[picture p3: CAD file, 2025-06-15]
ecad/MoodBearsKB/TOTEM3D/Kailh_switch_PG1350_optional.step
15.0 x 15.0 x 11.0 mm

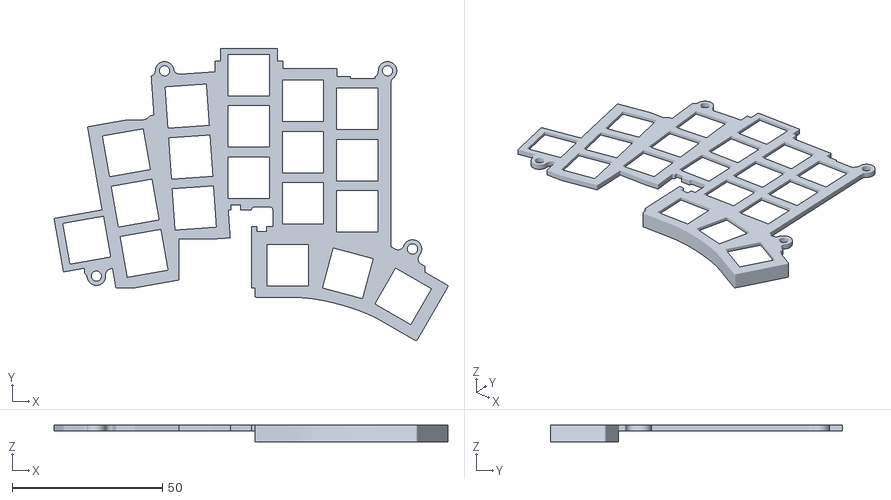
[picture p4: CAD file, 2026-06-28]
mcad/BLE/Redux/left/totem_left_plate.stl
131.1 x 97.3 x 5.65

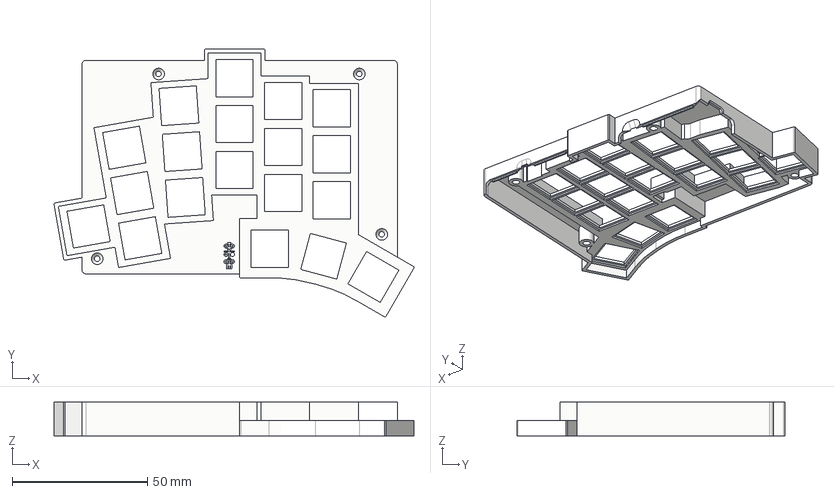
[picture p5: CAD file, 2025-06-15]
mcad/BLE/STEP/TOTEM_case_ble_top_L_V.08.step
133.1 x 99.0 x 12.5 mm

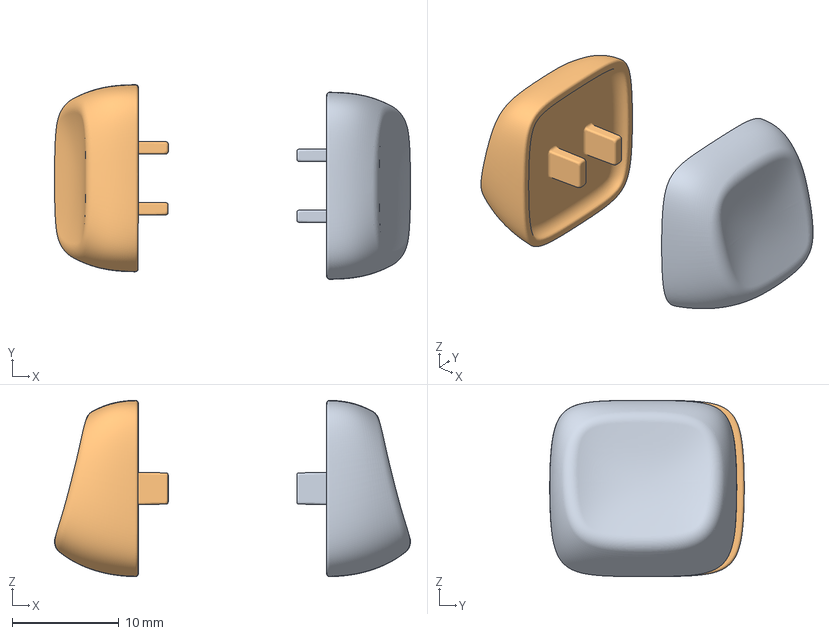
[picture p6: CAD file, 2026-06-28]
mcad/KLP-Lame-Keycaps/Printing/[Choc] Normal Tilted.3mf
33.3 x 18.2 x 16.5 mm
[Choc] Normal Tilted - FDM.stl x 2

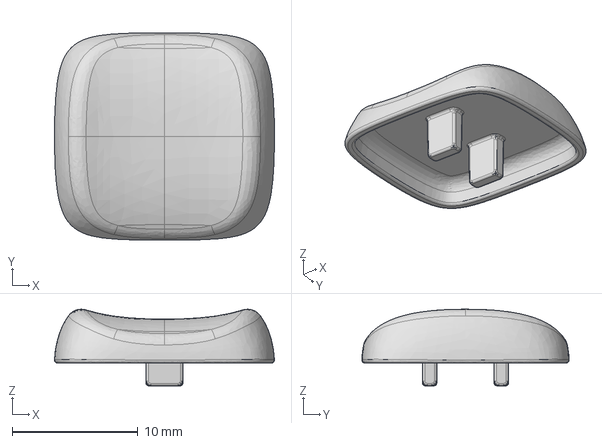
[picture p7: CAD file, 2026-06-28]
mcad/KLP-Lame-Keycaps/STEP/Choc Stem + Choc Size/90 deg Rotated/Choc_Stem_Choc_Size_Saddle_90deg.step
17.5 x 16.5 x 6.08 mm

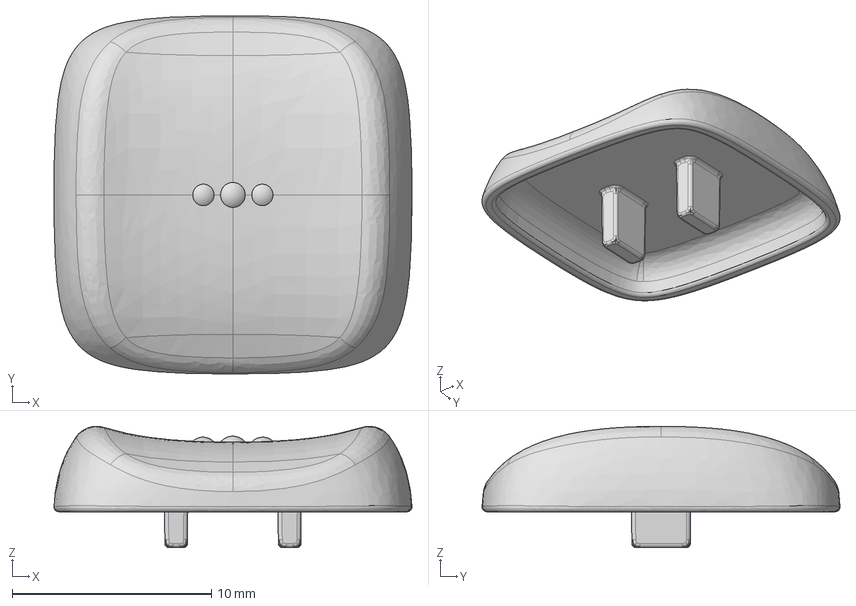
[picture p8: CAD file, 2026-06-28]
mcad/KLP-Lame-Keycaps/STEP/Choc Stem + MX Size/Choc_Stem_MX_Size_Saddle_Homing.step
18.0 x 18.0 x 6.09 mm

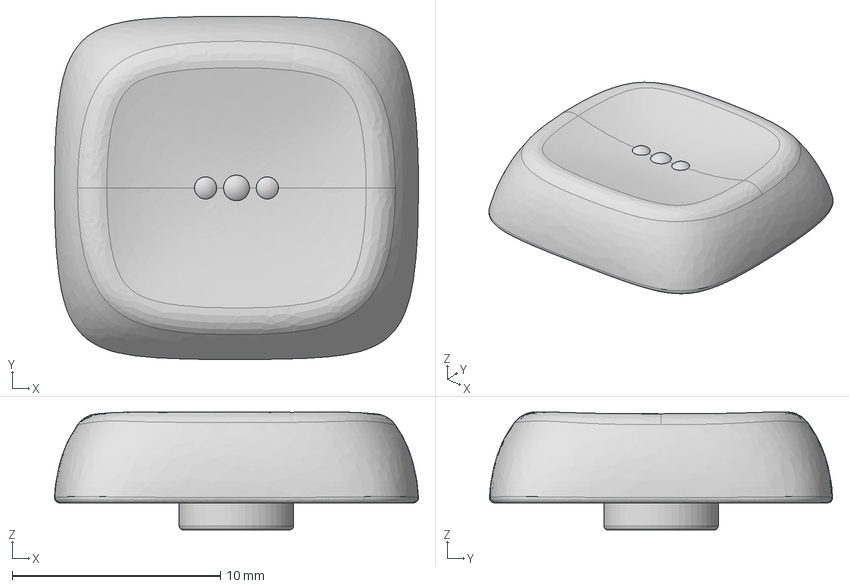
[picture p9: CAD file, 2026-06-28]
mcad/KLP-Lame-Keycaps/STEP/MX Stem + Choc Size/MX_Stem_Choc_Size_Normal_Homing.step
17.5 x 16.5 x 5.67 mm

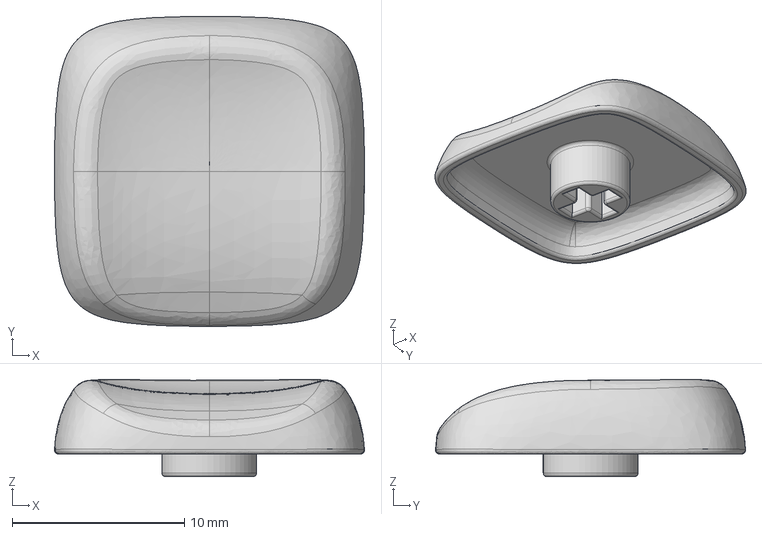
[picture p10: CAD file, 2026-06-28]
mcad/KLP-Lame-Keycaps/STEP/MX Stem + MX Size/MX_Stem_MX_Size_Thumb.step
18.0 x 18.0 x 5.64 mm

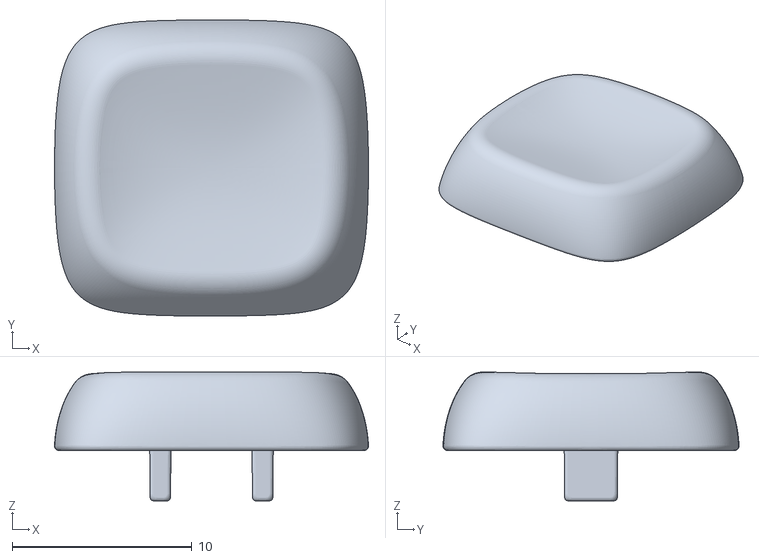
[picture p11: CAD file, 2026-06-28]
mcad/KLP-Lame-Keycaps/STL/Choc Stem + Choc Size/Smino Edits/[Choc] Normal - FDM.stl
17.5 x 16.5 x 7.17

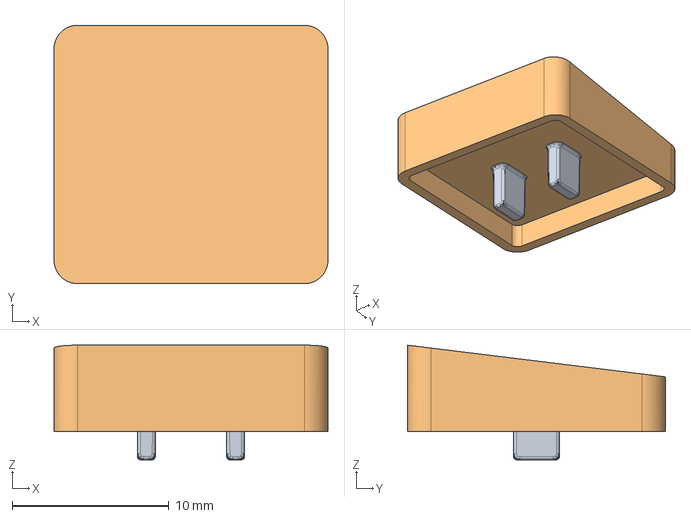
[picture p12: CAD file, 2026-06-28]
mcad/MoteCaps/mote-angled.step
17.5 x 16.5 x 7.33 mm

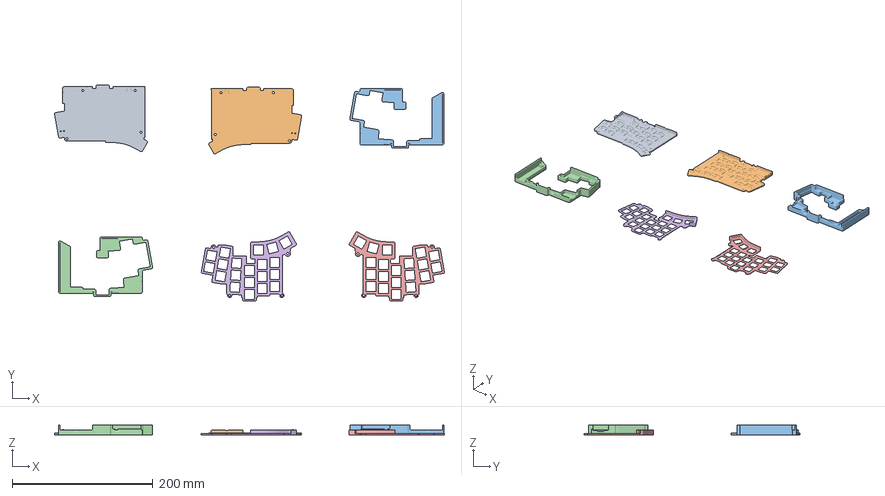
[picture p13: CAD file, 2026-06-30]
mcad/slices/MBKB.3mf
553.7 x 306.5 x 13.5 mm
BaseL.stl
BaseR.stl
HatL.stl
HatR.stl
SwitchPlateR.stl
SwitchPlateL.stl

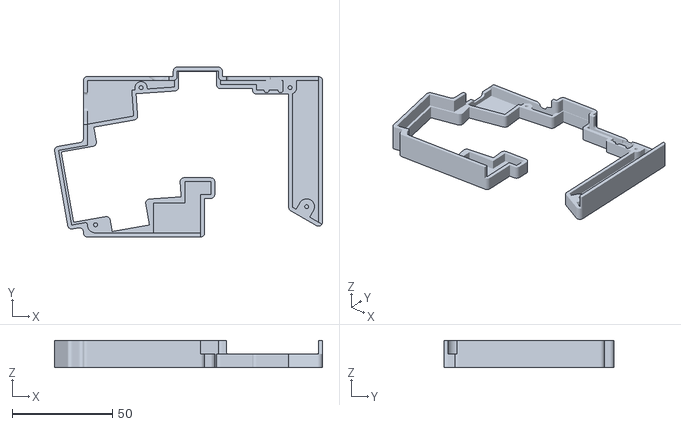
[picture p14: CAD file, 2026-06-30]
mcad/slices/stl/HatR.stl
133.5 x 84.7 x 13.5

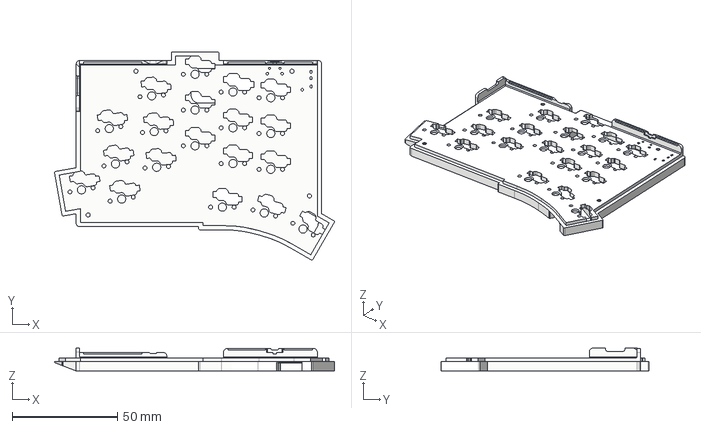
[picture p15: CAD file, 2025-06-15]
mcad/tenting/BLE/step/TOTEMcase_v08_6mm_BLE_Tenting_Bottom_L.step
133.1 x 99.0 x 10.9 mm

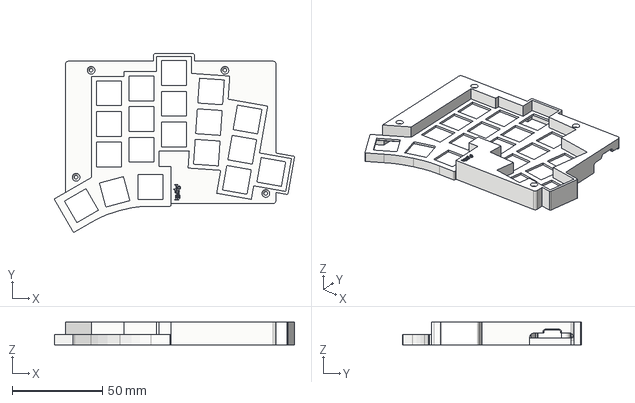
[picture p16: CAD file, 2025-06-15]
mcad/USB/STEP/TOTEM_case_usb_top_R_V.08.step
133.1 x 99.0 x 12.5 mm

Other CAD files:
mcad/BLE/Redux/right/totem_right_plate.stl
mcad/KLP-Lame-Keycaps/STEP/Choc Stem + Choc Size/Choc_Stem_Choc_Size_Saddle.step
mcad/tenting/TRX/STEP/TOTEMcase_v08_6mm_TRX_Tenting_Bottom_R.step
mcad/tenting/USB/STEP/TOTEMcase_v08_6mm_USB_Tenting_Bottom_R.step
ecad/MoodBearsKB/TOTEM3D/D_SOD-123.step
ecad/MoodBearsKB/TOTEM3D/Kailh_socket_PG1350_optional.STEP
ecad/MoodBearsKB/TOTEM3D/MSK12C02.STEP
ecad/MoodBearsKB/TOTEM3D/PJ320A.STEP
ecad/MoodBearsKB/TOTEM3D/SW_SKHLLC.step
ecad/MoodBearsKB/TOTEM3D/XIAO-BLE.step
mcad/BLE/Redux/left/totem_ble_left_bottom_hotswap.stl
mcad/BLE/Redux/left/totem_ble_left_top_no_logo_m2_inserts.stl
mcad/BLE/Redux/right/totem_ble_right_bottom_hotswap.stl
mcad/BLE/Redux/right/totem_ble_right_top_no_logo_m2_inserts.stl
mcad/BLE/STEP/TOTEM_case_ble_bottom_L_V.08.step
mcad/BLE/STEP/TOTEM_case_ble_bottom_R_V.08.step
mcad/BLE/STEP/TOTEM_case_ble_top_R_V.08.step
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

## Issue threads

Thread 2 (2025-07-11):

Y-Switch not Working

s-grundner, 2025-07-11:
Potential Hardware Bug? Y-Button (Lower Left Pinky) Not working, but right side is.

- Verify by trying out other Keys on this switch
- Try if other switches don't send Y keycode either
- Check if Keyboardmatrix is Correctly setup
- Check schematic and PCB
- Test with multimeter for a connection
- Finally Test with serial monitor

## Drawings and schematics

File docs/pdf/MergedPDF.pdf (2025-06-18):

xiao-ble DR5 | DR4 SWR10DR10 | DR9 SWR9 SWR5
B J1 MJ-4PP-9 | RSW1

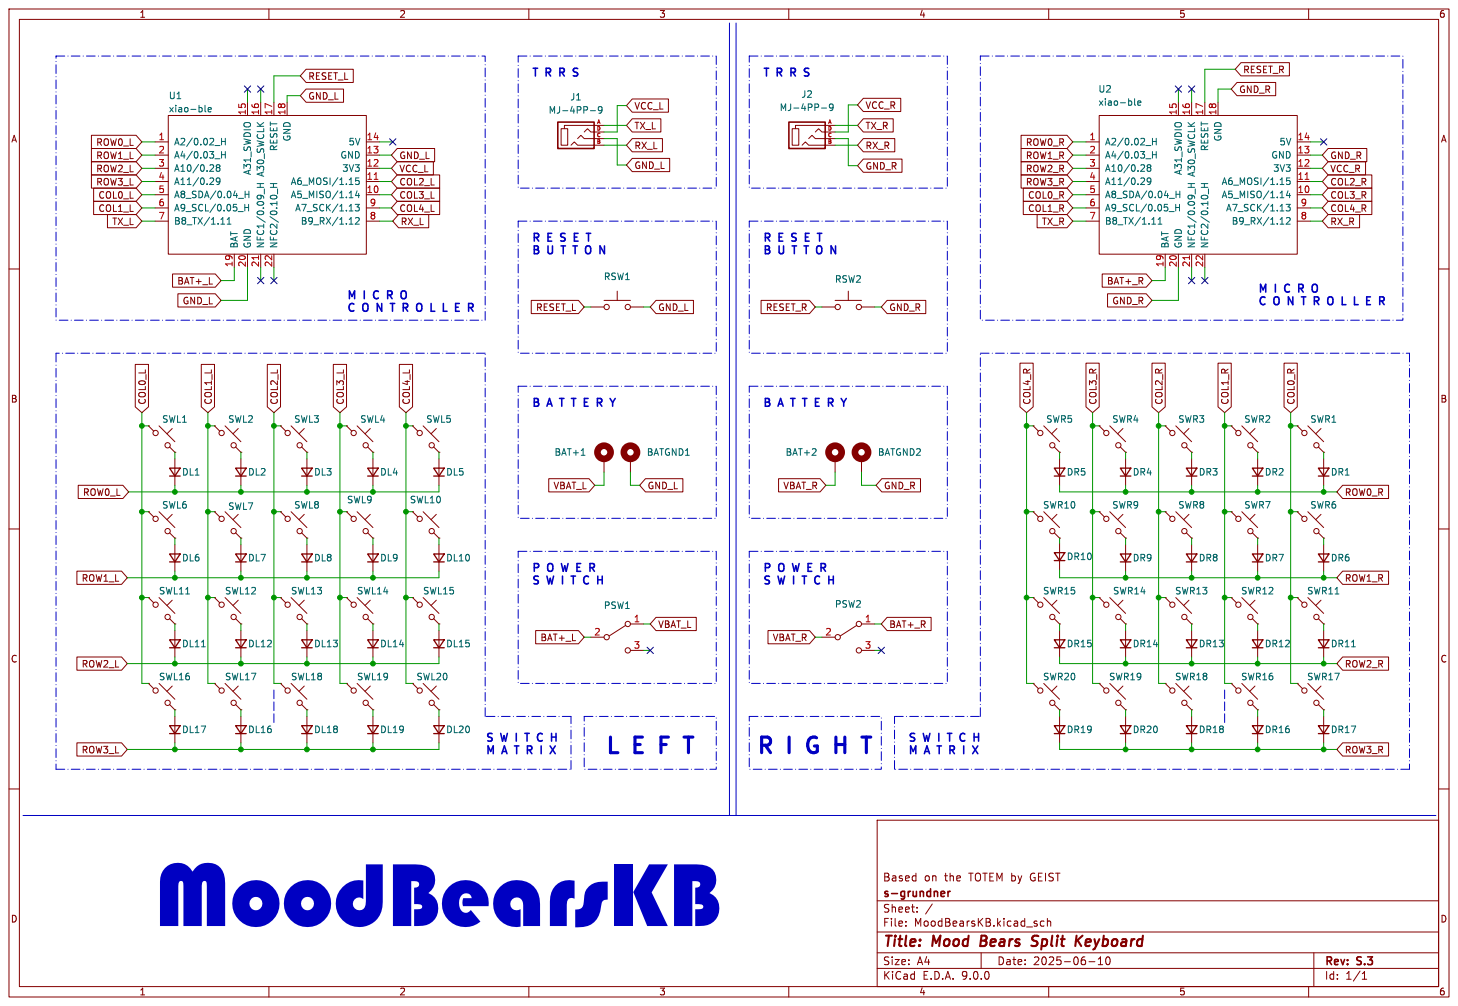
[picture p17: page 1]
D Date: 2025-06-10 KiCad; E.D.A. 9.0.0 Size: A4; Rev: S.3; File: MoodBearsKB.kicad_sch Sheet: / s-grundner Based; on the; TOTEM; by GEIST; SWL6; SWR15; SWR14 DL2; SWR20DR15 SWL7 DL1; SWL8; SWL9 DL3 DL8; DR18 SWL17DL16 DL12 SWL16DL17; DR11 SWL15 DL11; A2/0.02_H 1 A4/0.03_H 2 A10/0.28 3 A11/0.29 4 A8_SDA/0.04_H 5 A9_SCL/0.05_H 6 B8_TX/1.11 7; BAT 19; A³¹_SWDIO ¹⁵ GND 20; A³⁰_SWCLK ¹⁶ NFC¹/0.09_H 21; RESET 17 NFC²/0.10_H 22; GND ¹⁸; 5V 14 GND 13; 3V3 12 A6_MOSI/1.15; 11 A5_MISO/1.14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

Id: 1/1 Title: Mood Bears Split Keyboard

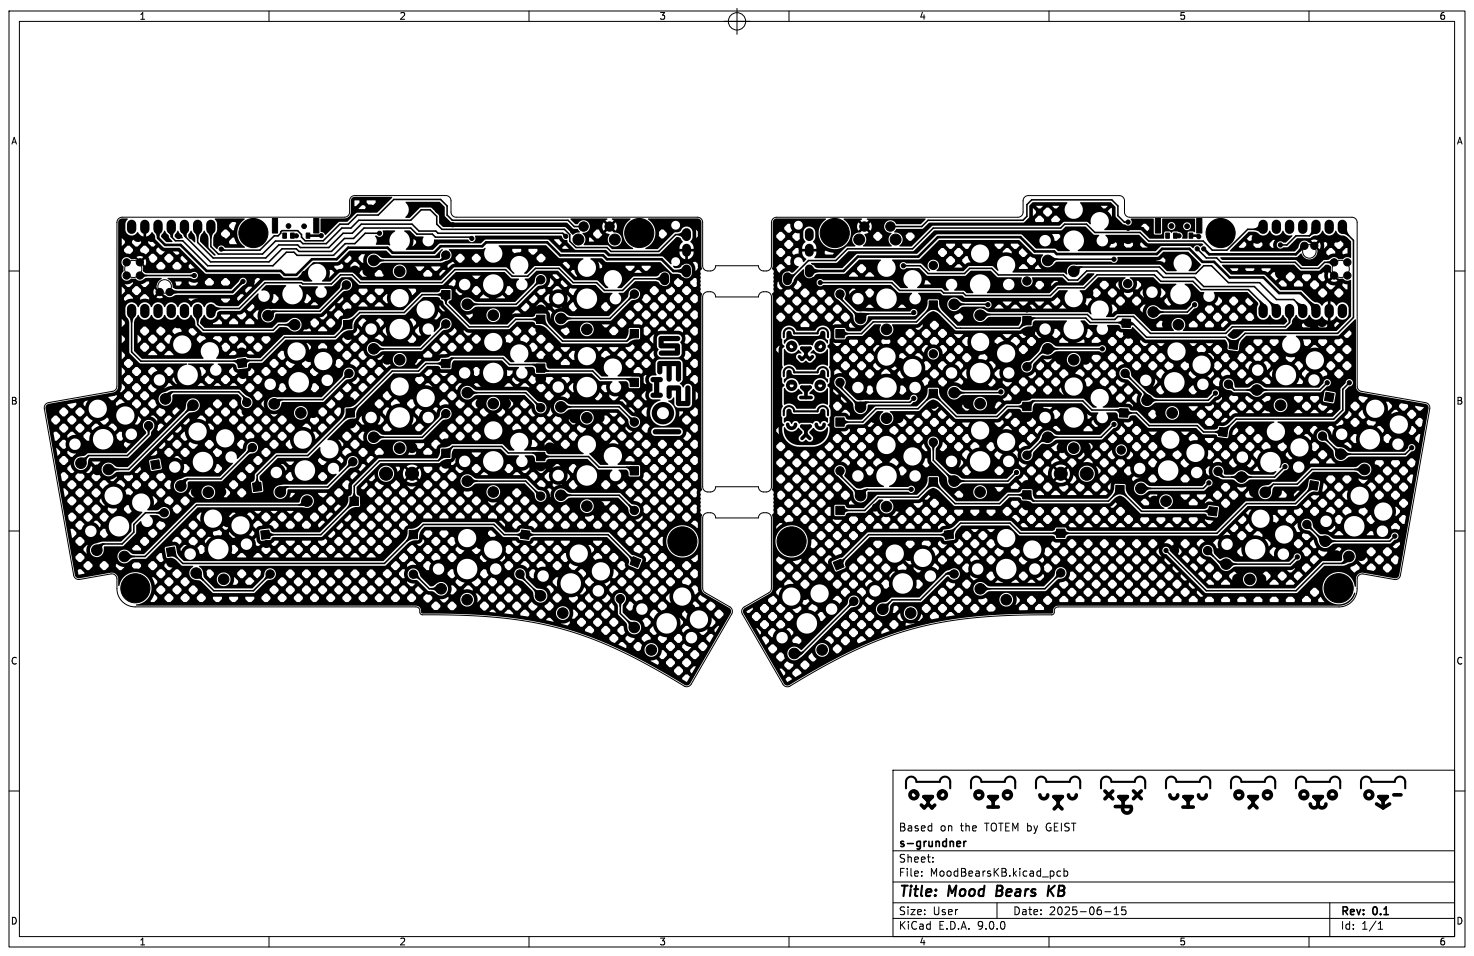
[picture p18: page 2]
D Date: 2025-06-15 KiCad; E.D.A. 9.0.0 Size: User; Rev: 0.1; File:; MoodBearsKB.kicad_pcb Sheet: s-grundner Based; on the; TOTEM; by GEIST

Id: 1/1 Title: Mood Bears KB

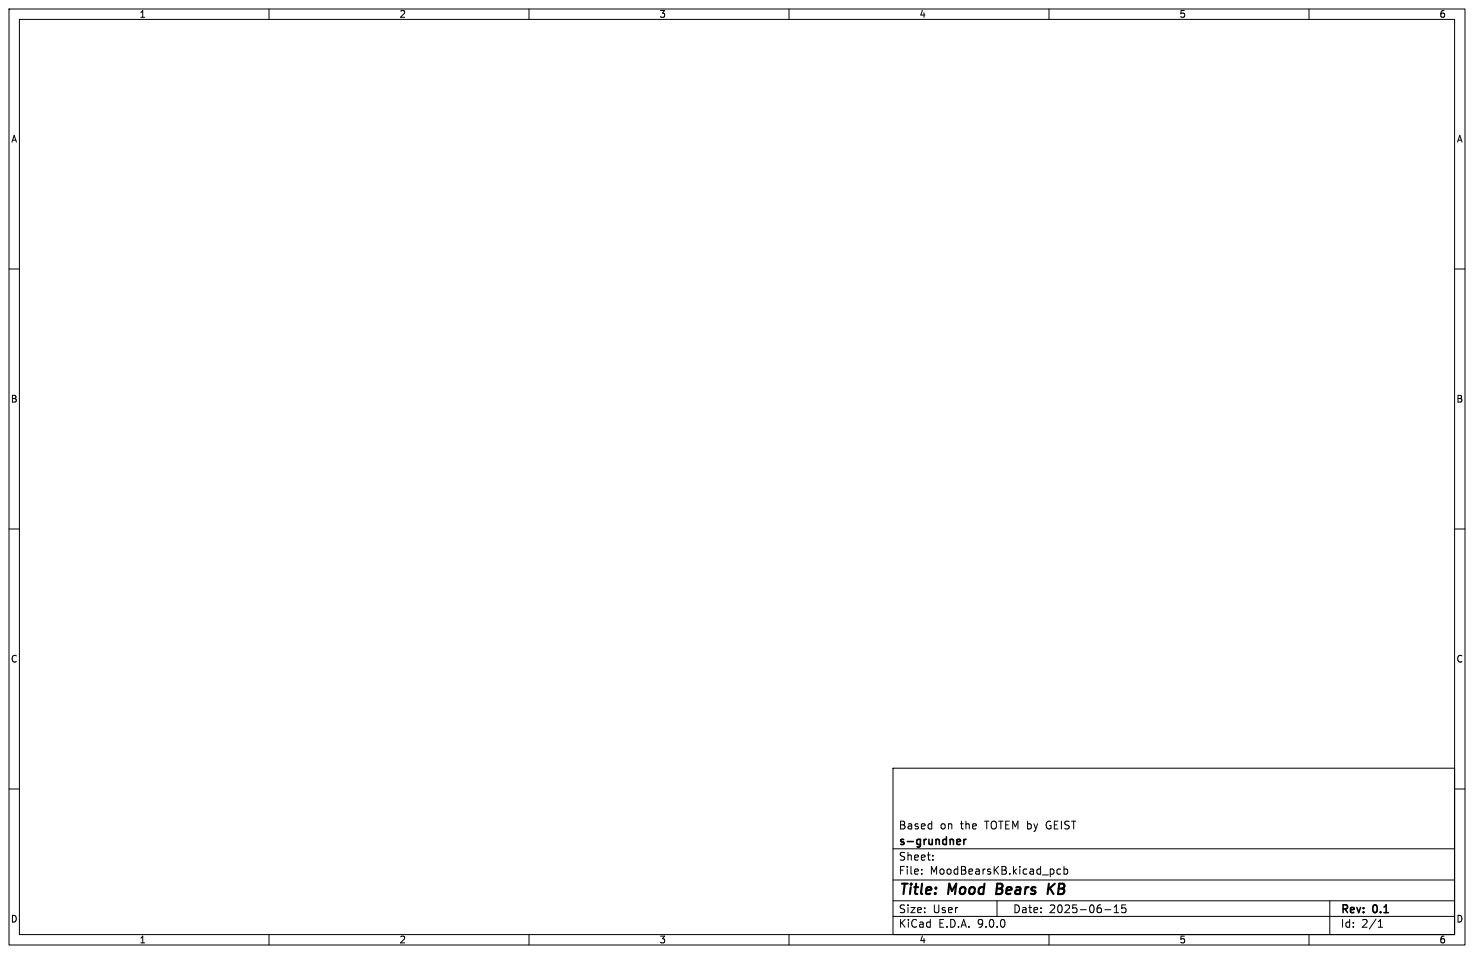
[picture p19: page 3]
File:; MoodBearsKB.kicad_pcb Sheet: s-grundner Based; on the; TOTEM; by GEIST

Id: 2/1 Title: Mood Bears KB

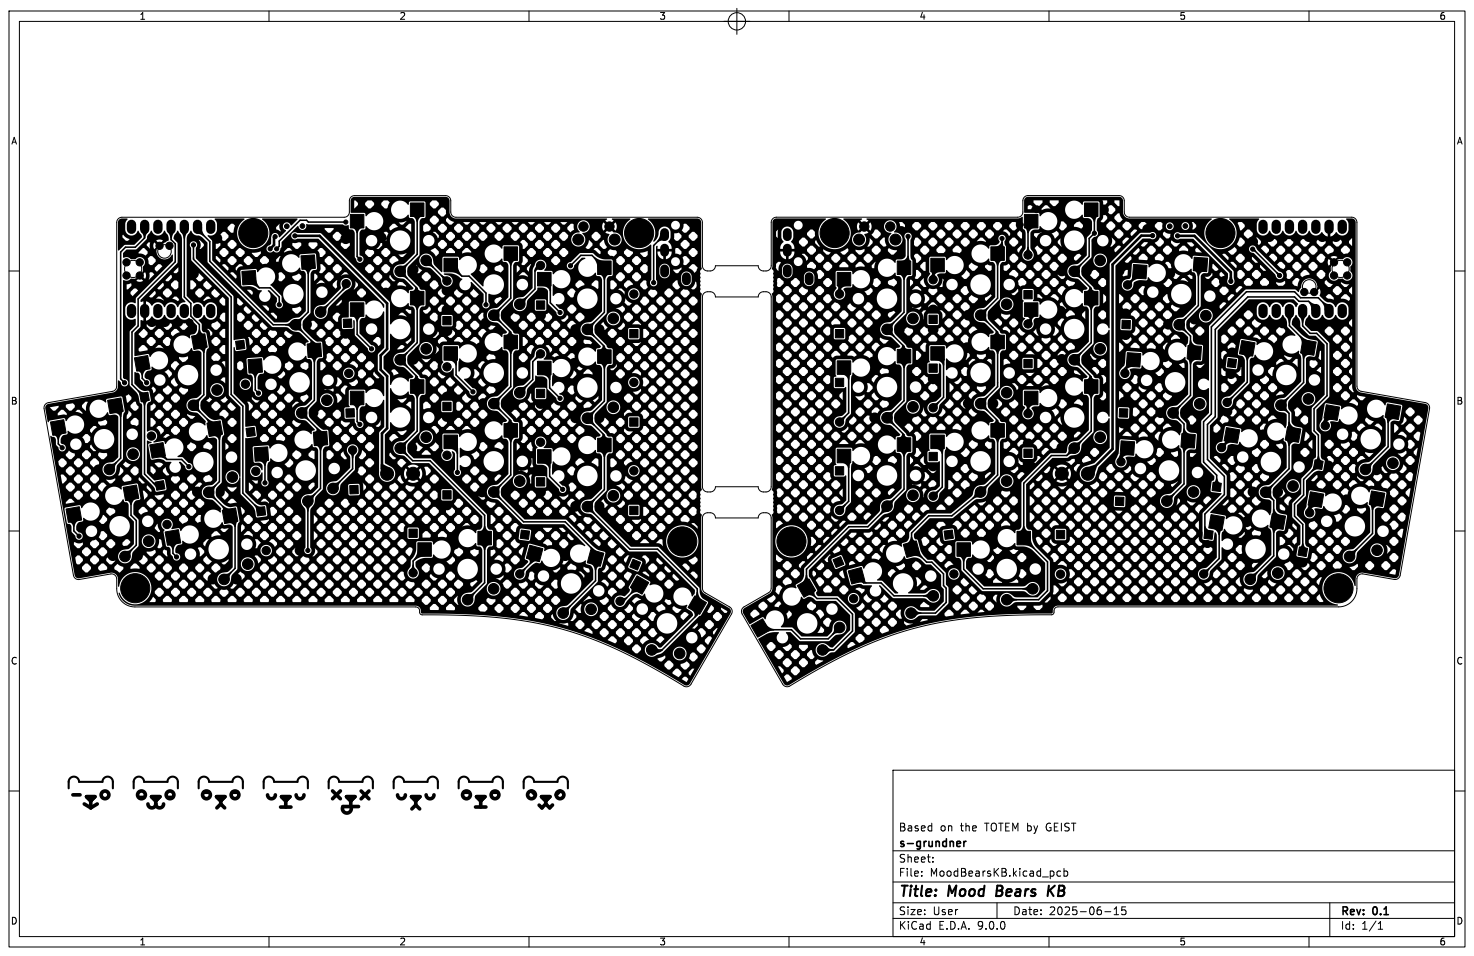
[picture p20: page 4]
File:; MoodBearsKB.kicad_pcb Sheet: s-grundner Based; on the; TOTEM; by GEIST

Id: 1/1 Title: Mood Bears KB

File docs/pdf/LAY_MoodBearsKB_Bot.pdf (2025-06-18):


Id: 1/1 Title: Mood Bears KB

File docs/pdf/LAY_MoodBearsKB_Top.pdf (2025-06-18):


Id: 1/1 Title: Mood Bears KB


Id: 2/1 Title: Mood Bears KB

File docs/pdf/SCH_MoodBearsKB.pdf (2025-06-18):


Id: 1/1 Title: Mood Bears Split Keyboard

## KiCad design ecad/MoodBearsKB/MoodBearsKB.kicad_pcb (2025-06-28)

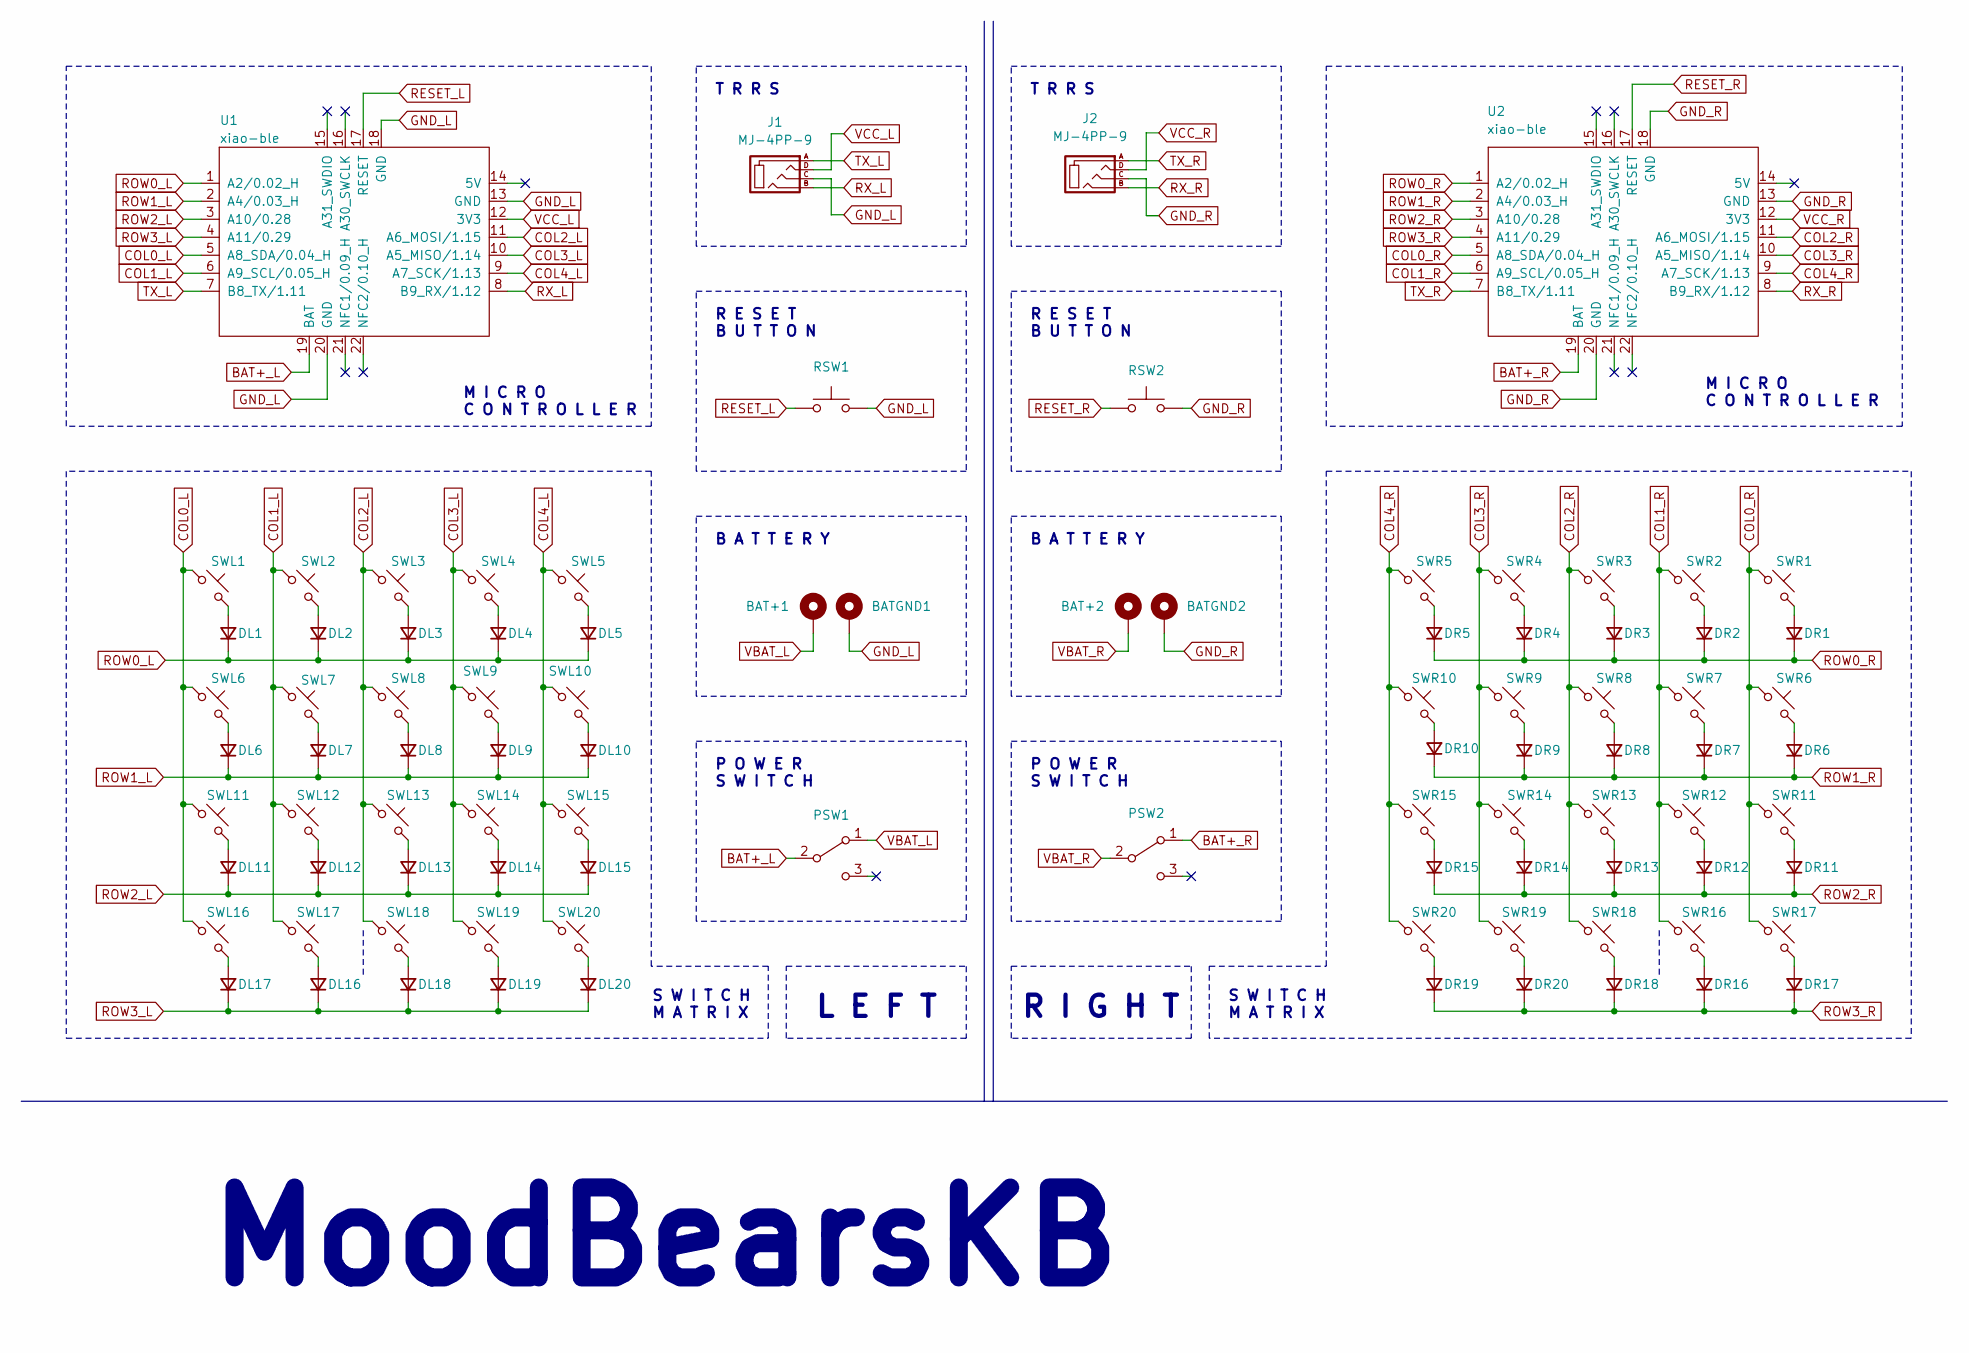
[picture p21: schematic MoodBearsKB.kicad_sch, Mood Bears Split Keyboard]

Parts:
BAT+1, BAT+2: +; BatteryPad
BATGND1, BATGND2: -; BatteryPad
DL1, DL2, DL3, DL4, DL5, DL6, DL7, DL8, DL9, DL10, DL11, DL12, DL13, DL14, DL15, DL16, DL17, DL18, DL19, DL20: D_Small; Diode_SOD27
DR1, DR2, DR3, DR4, DR5, DR6, DR7, DR8, DR9, DR10, DR11, DR12, DR13, DR14, DR15, DR16, DR17, DR18, DR19, DR20: D_Small; Diode_SOD27
J1, J2: MJ-4PP-9; MJ-4PP-9_1side
PSW1, PSW2: SW_SPDT; MSK12C02
RSW1, RSW2: SW_Push; SKHLLCA010
SWL1, SWL2, SWL3, SWL4, SWL5, SWL6, SWL7, SWL8, SWL9, SWL10, SWL11, SWL12, SWL13, SWL14, SWL15, SWL16, SWL17, SWL18, SWL19, SWL20: SW_Push_45deg; Kailh_socket_PG1350_optional
SWR1, SWR2, SWR3, SWR4, SWR5, SWR6, SWR7, SWR8, SWR9, SWR10, SWR11, SWR12, SWR13, SWR14, SWR15, SWR16, SWR17, SWR18, SWR19, SWR20: SW_Push_45deg; Kailh_socket_PG1350_optional
U1, U2: xiao-ble; xiao-ble-smd-cutout

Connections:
BAT+_L: PSW1.2 (B), U1.19 (BAT)
BAT+_R: PSW2.1 (A), U2.19 (BAT)
COL0_L: SWL1.1, SWL6.1, SWL11.1, SWL16.1, U1.5 (A8_SDA/0.04_H)
COL0_R: SWR1.1, SWR6.1, SWR11.1, SWR17.1, U2.5 (A8_SDA/0.04_H)
COL1_L: SWL2.1, SWL7.1, SWL12.1, SWL17.1, U1.6 (A9_SCL/0.05_H)
COL1_R: SWR2.1, SWR7.1, SWR12.1, SWR16.1, U2.6 (A9_SCL/0.05_H)
COL2_L: SWL3.1, SWL8.1, SWL13.1, SWL18.1, U1.11 (A6_MOSI/1.15)
COL2_R: SWR3.1, SWR8.1, SWR13.1, SWR18.1, U2.11 (A6_MOSI/1.15)
COL3_L: SWL4.1, SWL9.1, SWL14.1, SWL19.1, U1.10 (A5_MISO/1.14)
COL3_R: SWR4.1, SWR9.1, SWR14.1, SWR19.1, U2.10 (A5_MISO/1.14)
COL4_L: SWL5.1, SWL10.1, SWL15.1, SWL20.1, U1.9 (A7_SCK/1.13)
COL4_R: SWR5.1, SWR10.1, SWR15.1, SWR20.1, U2.9 (A7_SCK/1.13)
GND_L: BATGND1.1, J1.C, RSW1.1, U1.13 (GND), U1.18 (GND), U1.20 (GND)
GND_R: BATGND2.1, J2.C, RSW2.2, U2.13 (GND), U2.18 (GND), U2.20 (GND)
unnamed: DL1.2 (A), SWL1.2
unnamed: DL2.2 (A), SWL2.2
unnamed: DL3.2 (A), SWL3.2
unnamed: DL4.2 (A), SWL4.2
unnamed: DL5.2 (A), SWL5.2
unnamed: DL6.2 (A), SWL6.2
unnamed: DL7.2 (A), SWL7.2
unnamed: DL8.2 (A), SWL8.2
unnamed: DL9.2 (A), SWL9.2
unnamed: DL10.2 (A), SWL10.2
unnamed: DL11.2 (A), SWL11.2
unnamed: DL12.2 (A), SWL12.2
unnamed: DL13.2 (A), SWL13.2
unnamed: DL14.2 (A), SWL14.2
unnamed: DL15.2 (A), SWL15.2
unnamed: DL16.2 (A), SWL17.2
unnamed: DL17.2 (A), SWL16.2
unnamed: DL18.2 (A), SWL18.2
unnamed: DL19.2 (A), SWL19.2
unnamed: DL20.2 (A), SWL20.2
unnamed: DR1.2 (A), SWR1.2
unnamed: DR2.2 (A), SWR2.2
unnamed: DR3.2 (A), SWR3.2
unnamed: DR4.2 (A), SWR4.2
unnamed: DR5.2 (A), SWR5.2
unnamed: DR6.2 (A), SWR6.2
unnamed: DR7.2 (A), SWR7.2
unnamed: DR8.2 (A), SWR8.2
unnamed: DR9.2 (A), SWR9.2
unnamed: DR10.2 (A), SWR10.2
unnamed: DR11.2 (A), SWR11.2
unnamed: DR12.2 (A), SWR12.2
unnamed: DR13.2 (A), SWR13.2
unnamed: DR14.2 (A), SWR14.2
unnamed: DR15.2 (A), SWR15.2
unnamed: DR16.2 (A), SWR16.2
unnamed: DR17.2 (A), SWR17.2
unnamed: DR18.2 (A), SWR18.2
unnamed: DR19.2 (A), SWR20.2
unnamed: DR20.2 (A), SWR19.2
RESET_L: RSW1.2, U1.17 (RESET)
RESET_R: RSW2.1, U2.17 (RESET)
ROW0_L: DL1.1 (K), DL2.1 (K), DL3.1 (K), DL4.1 (K), DL5.1 (K), U1.1 (A2/0.02_H)
ROW0_R: DR1.1 (K), DR2.1 (K), DR3.1 (K), DR4.1 (K), DR5.1 (K), U2.1 (A2/0.02_H)
ROW1_L: DL6.1 (K), DL7.1 (K), DL8.1 (K), DL9.1 (K), DL10.1 (K), U1.2 (A4/0.03_H)
ROW1_R: DR6.1 (K), DR7.1 (K), DR8.1 (K), DR9.1 (K), DR10.1 (K), U2.2 (A4/0.03_H)
ROW2_L: DL11.1 (K), DL12.1 (K), DL13.1 (K), DL14.1 (K), DL15.1 (K), U1.3 (A10/0.28)
ROW2_R: DR11.1 (K), DR12.1 (K), DR13.1 (K), DR14.1 (K), DR15.1 (K), U2.3 (A10/0.28)
ROW3_L: DL16.1 (K), DL17.1 (K), DL18.1 (K), DL19.1 (K), DL20.1 (K), U1.4 (A11/0.29)
ROW3_R: DR16.1 (K), DR17.1 (K), DR18.1 (K), DR19.1 (K), DR20.1 (K), U2.4 (A11/0.29)
RX_L: J1.B, U1.8 (B9_RX/1.12)
RX_R: J2.B, U2.8 (B9_RX/1.12)
TX_L: J1.A, U1.7 (B8_TX/1.11)
TX_R: J2.A, U2.7 (B8_TX/1.11)
VBAT_L: BAT+1.1, PSW1.1 (A)
VBAT_R: BAT+2.1, PSW2.2 (B)
VCC_L: J1.D, U1.12 (3V3)
VCC_R: J2.D, U2.12 (3V3)

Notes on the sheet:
M I C R O C O N T R O L L E R
T R R S
R E S E T B U T T O N
S W I T C H M A T R I X
P O W E R S W I T C H
MoodBearsKB
B A T T E R Y
R I G H T
L E F T

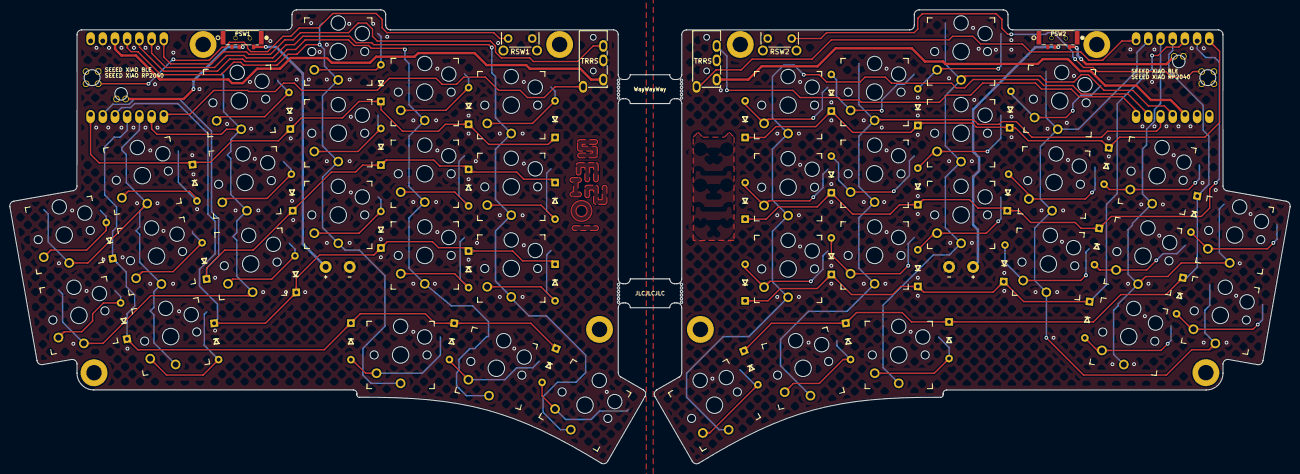
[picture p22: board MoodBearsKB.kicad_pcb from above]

Board: 2 copper layers, 266.5 x 94.5 mm, 92 parts (0 on the bottom side), 72 nets.

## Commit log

2025-06-15 initial commit - ready for prod
    [D_SOD-123.step, Kailh_socket_PG1350_optional.STEP, Kailh_switch_PG1350_optional.step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]
2025-06-15 added pcbway Prod Files and specified order number location
    [MoodBearsKB.kicad_pcb, MoodBearsKB.kicad_pcb_bom.csv, MoodBearsKB.kicad_pcb_positions.csv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]
2025-06-18 sent to PCBWay!
    [MoodBearsKB.kicad_pcb, MoodBearsKB.kicad_pcb_bom.csv, MoodBearsKB.kicad_pcb_positions.csv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]
2025-06-18 Edit Schematic Footer
    [MoodBearsKB.kicad_sch]
2025-06-18 added documentation for schem and layout as pdf
    [MoodBearsKB.kicad_pcb]
2025-06-28 upd docs
    [MoodBearsKB.kicad_pcb]
2026-06-29 Rename board from seeeduino_xiao_ble to xiao_ble
2026-06-29 Update board references in build.yaml
2026-06-30 stls and firmware
    [BaseL.stl, BaseR.stl, Body1.3mf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]
2026-06-30 upload instructions
    [MBKB.3mf, [Choc] Normal Tilted.3mf]
2026-06-30 battery level reporing
    [MBKB.3mf]
